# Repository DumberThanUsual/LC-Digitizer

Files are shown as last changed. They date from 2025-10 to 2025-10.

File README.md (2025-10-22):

# LC Resonator Locator and Digitizer



## Second Year Group Project Hardware Element

This project is the hardware input element of my second year FPGA group project. 
The FPGA part was a hardware accelerated complex function plotter, taking coordinates of poles and zeros on the complex plane as inputs and displaying the result on an HDMI display.
The input hardware is a board that detects the positions of tokens that represent poles and zeros of different orders which can be placed on the board.

## Theory of Operation



The tokens are a capacitor and inductor in paralell, forming an LC resonator. The inductor is unshielded, allowing it to interact with external magnetic fields. 
They can be caused to resonate by an electromagnetic impulse generated by placing it on a coil and sending a pusle of current through it. 
The presence of the token can be detected by measuring the voltage on the coil after the original impulse and looking for the resonant frequency of the resonator.

Using this for detection and location of the tokens can be done by separating and multiplexing the detection loops into transmission and reception loops.
These loops can be elongated and placed perpendicularly on opposite sides of a PCB. Pulsing one Tx loop and listening on all Rx loops measures token presence on one row and scanning all Tx coils reveals the entire plane.

Measurement of tokens not located exactly within one intersection (cell) of Tx and Rx coils is done by measuring the amplitude of a cluster of responses and adjusting the final position proportionally. 
This requires the minimum spacing between tokens to be greater than twice the width of the coils.

Differentiating between types of tokens, representing differing orders of the poles and zeros, is done by varying the resonant frequencies of the tokens and measuring this in the response.

## Issues and Reflections

This project was designed with little time for development and refinement. The PCB had to be ordered within 2 weeks of the project start, with no second revision. This means there are some (very questionable) quirks in the design, including:
- "Row Amplifers": After some debate, we did not want to risk the expected sub-millivolt signal being lost in the multiplexers. To be safe, we added a 20dB amplifier for every row.
  Not only was the signal much larger than measured in the prototype, but the multiplexers do not affect the signal in a meaningful way. The capacitor between the gain-setting resistors and the reference is not necessary and nor is the entire row amplifier circuit.
  This saves 8 ICs, lots of board space and some cost.

- Slow loop driver ICs: The loop driver ICs are pulsed by pulsing their sleep pins, not the input pins. We did not read the datasheet properly - these ICs take 30µs to wake from sleep.
  Given this needs to be done 128 times per scan, at multiple scans per second, this is a big limiting factor in the update rate.
  Instead, the sleep pins should be tied low and the OE pins on the shift registers be pulsed instead.

- Slow OLED: The oled is of the I2C variety, running at 400kHz. Using a non-DMA library to drive it, this is very slow and stops the UI task from properly reading the rotary encoder inputs.

- Suicidal power managment: If there is a glitch in the power supply, it seems to be possible that the shift registers and driver ICs can be set to drive a loop, shorting the supply to ground and browning out the µC and preventing it from turning off the drivers.
  This does not cause damage to the board, but the power needs to be recycled before it will work again and is very annoying.

- Substandard firmware: The firmware became progressivly more rushed as time went on. This is especially visible in the liberal use of ```nop``` delays instead of proper freeRTOS and timer delays.

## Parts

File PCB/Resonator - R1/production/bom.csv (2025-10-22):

Designator | Footprint | Quantity | Value | LCSC Part #
C101 | 0603 | 1 | 62p
C103 | 0603 | 1 | 12p
C104 | 0603 | 1 | 27p
C105 | 0603 | 1 | 39p
C106 | 0603 | 1 | 56p
C107 | 0603 | 1 | 82p
C108 | 0603 | 1 | 120p
C109 | 0603 | 1 | 160p
C110 | 0603 | 1 | 220p
L101 | L | 1 | 1m
TP101, TP102 | 5mm 112.5 | 2 | TestPoint
TP103, TP104, TP105, TP106, TP107, TP108, TP109, TP110 | 7mm 20 | 8 | TestPoint

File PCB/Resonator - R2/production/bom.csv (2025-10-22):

Designator | Footprint | Quantity | Value | LCSC Part #
TP101, TP102 | TestPoint_Pad_D1.0mm | 2 | TestPoint

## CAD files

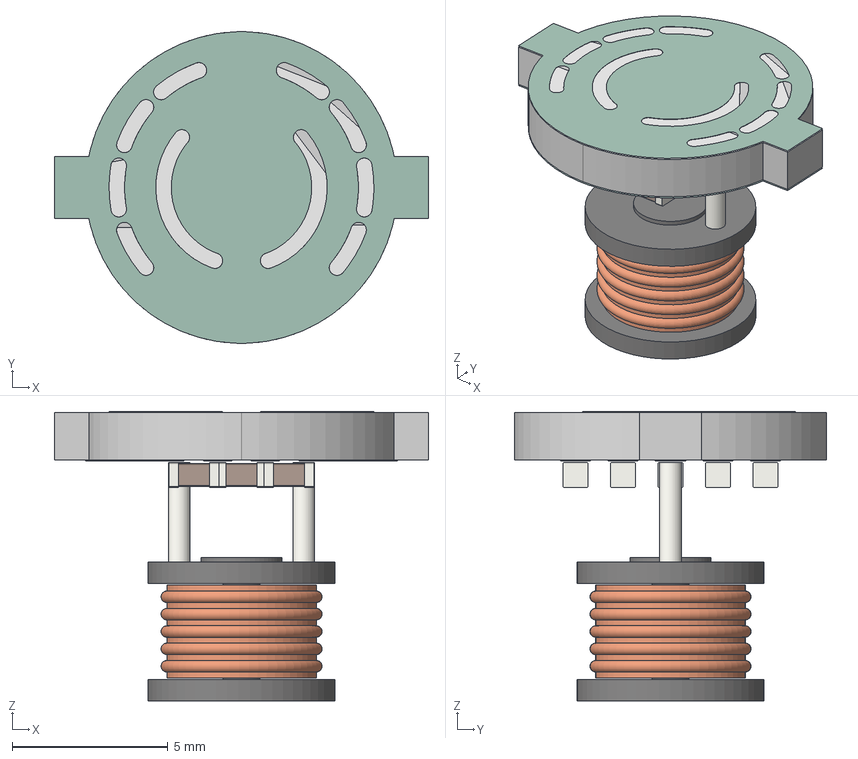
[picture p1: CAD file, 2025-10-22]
PCB/Resonator - R1/Resonator - R1.step
12.0 x 10.00 x 9.30 mm
C_0603_1608Metric x 9
L_Radial_D6.0mm_P4.00mm
Resonator - R1_pad
Resonator - R1_silkscreen
Resonator - R1_soldermask
Resonator - R1_PCB

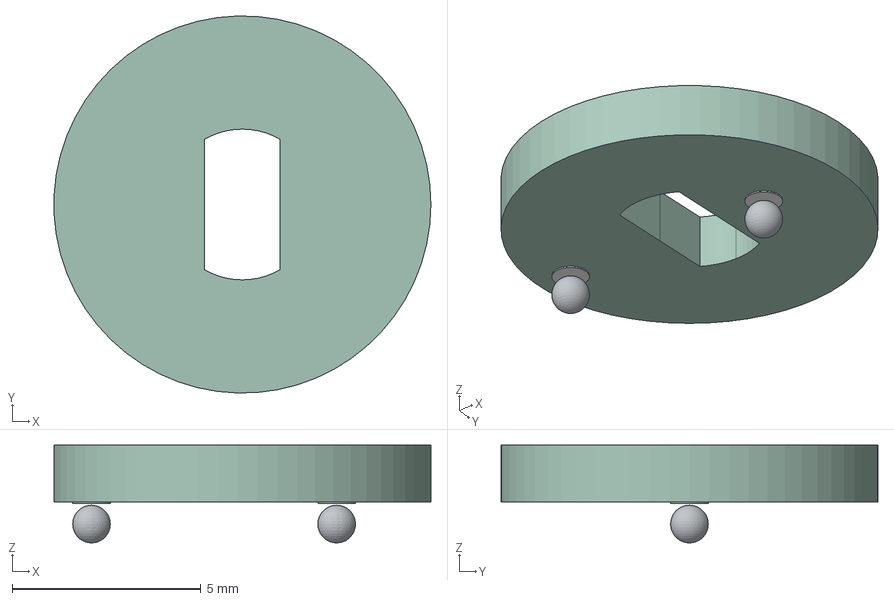
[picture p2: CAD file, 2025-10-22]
PCB/Resonator - R2/Resonator - R2.step
9.99 x 10.00 x 2.59 mm
Resonator - R2_pad
Resonator - R2_PCB

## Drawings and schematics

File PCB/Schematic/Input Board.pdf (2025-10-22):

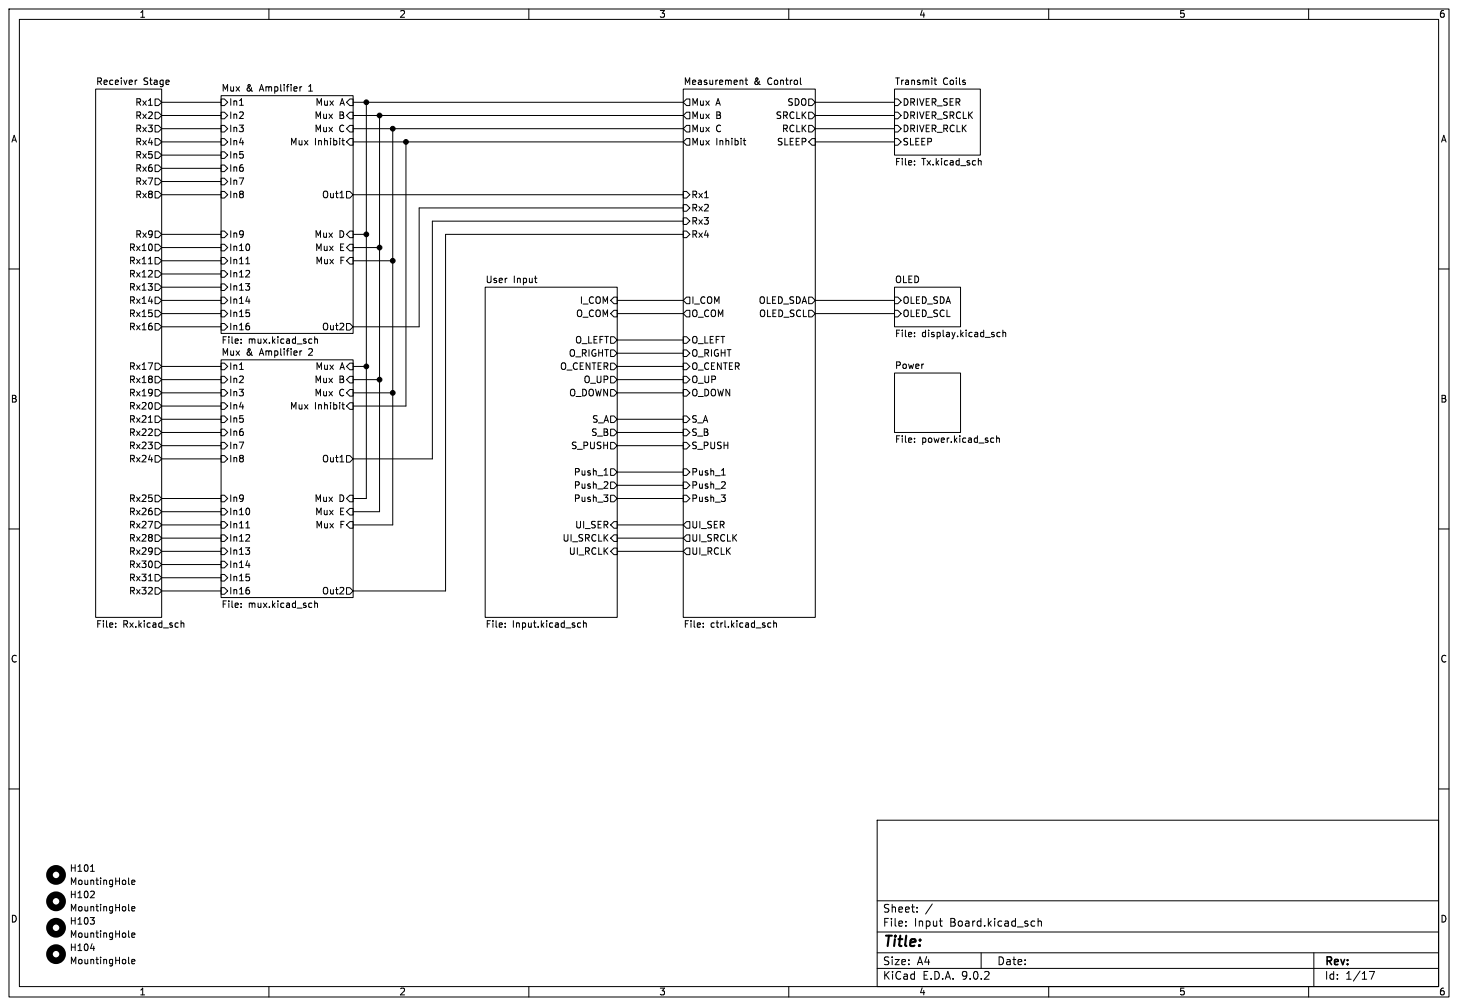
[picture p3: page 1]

Transmit Coils File: Tx.kicad_sch

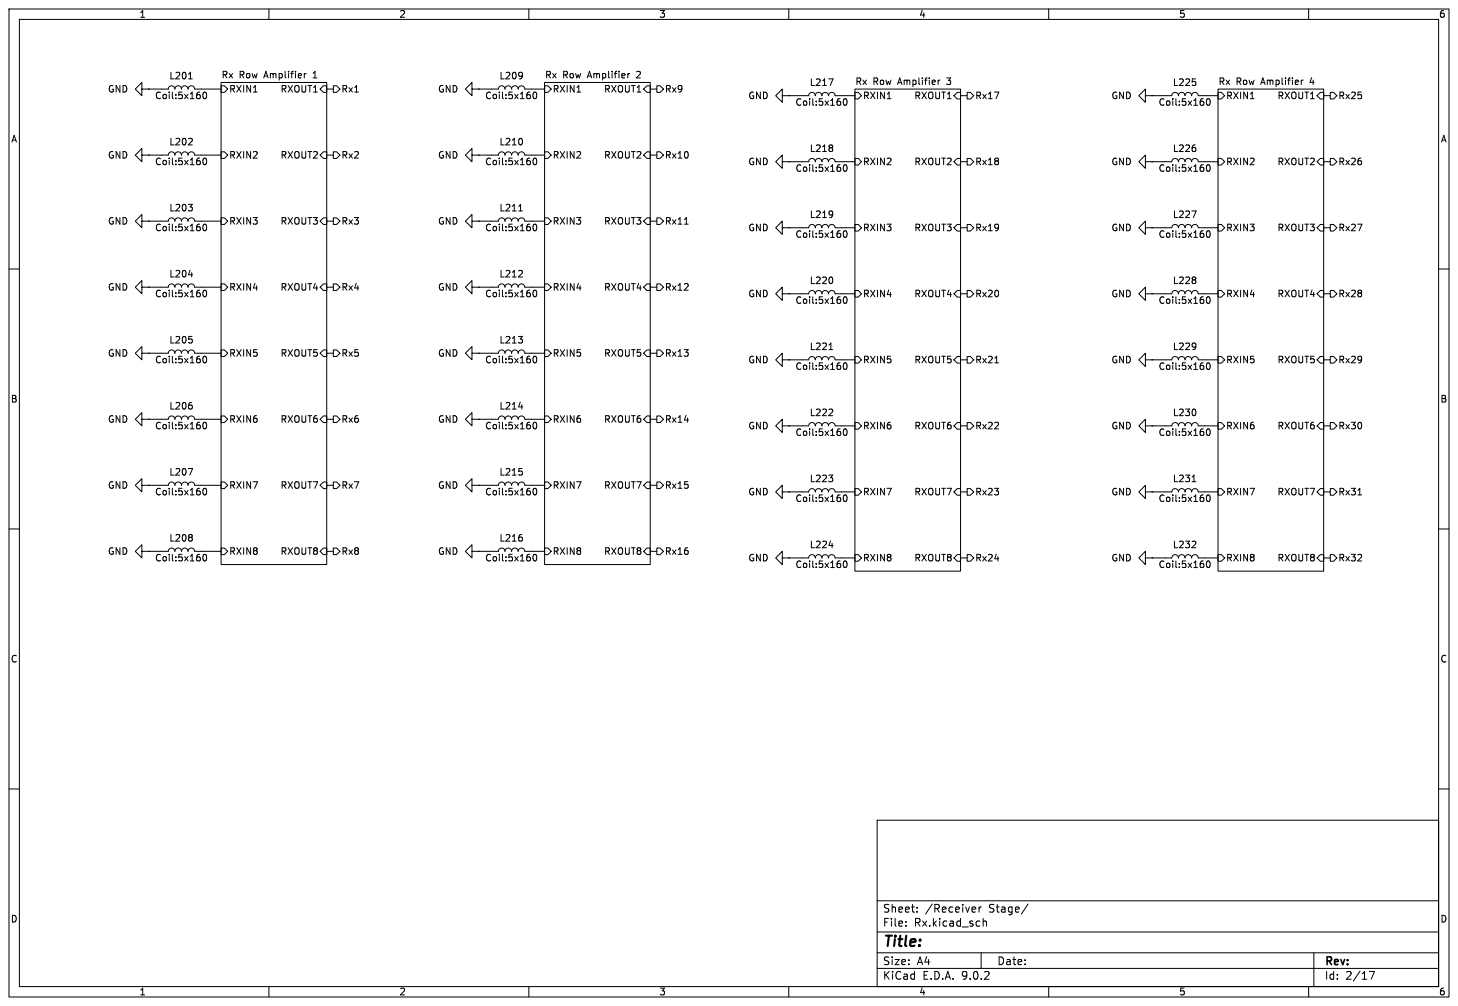
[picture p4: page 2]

L225 Coil:5x160 GND GND GND GND

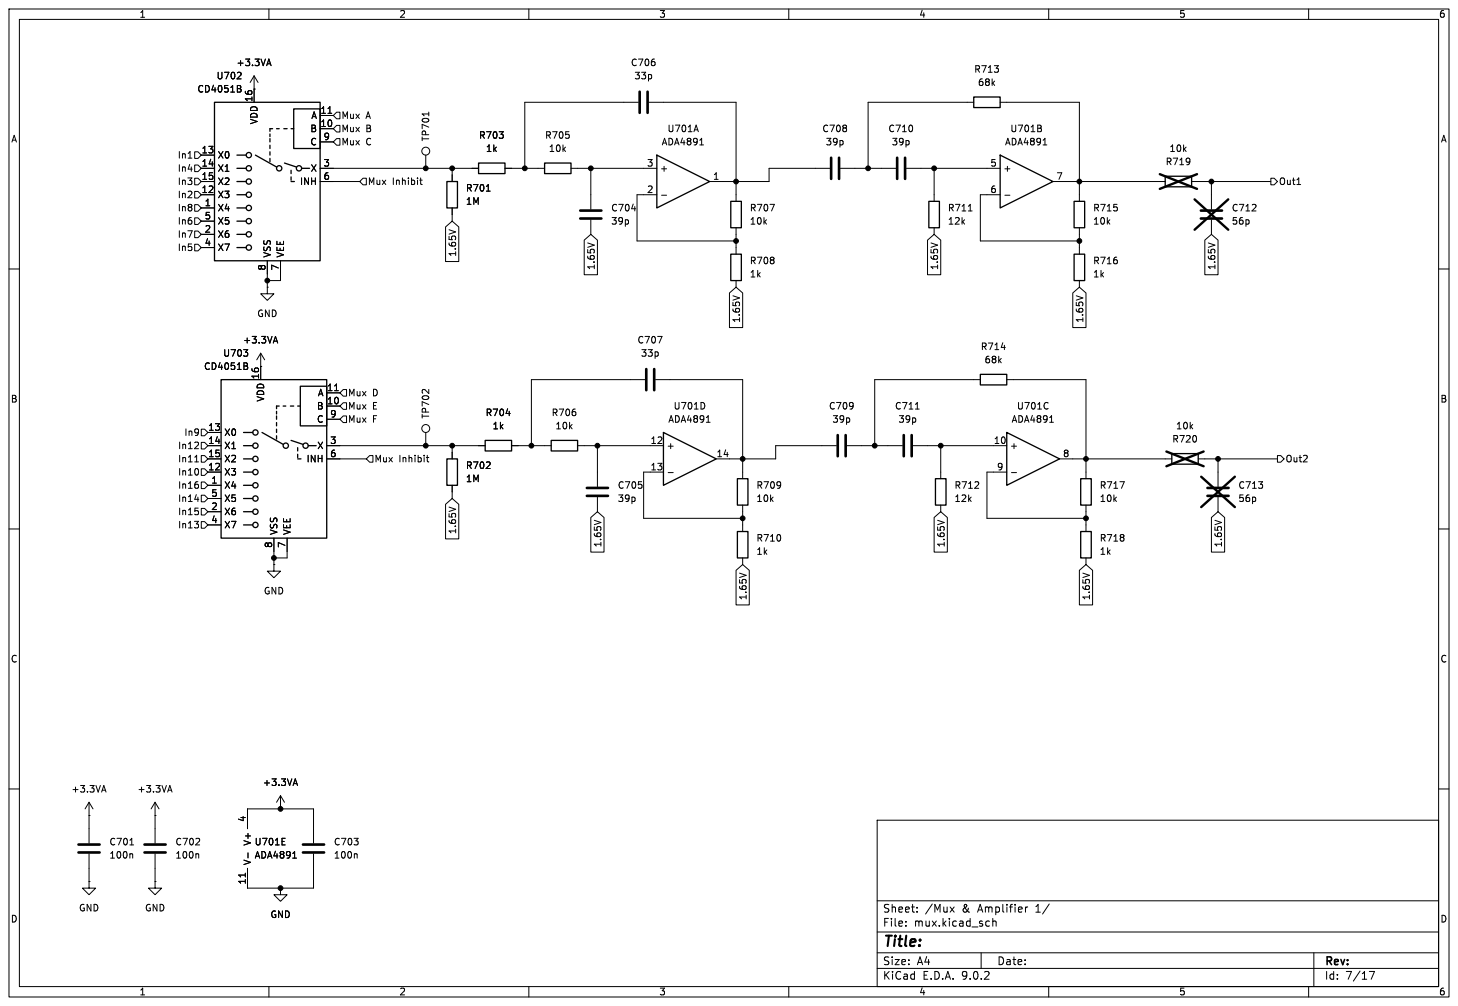
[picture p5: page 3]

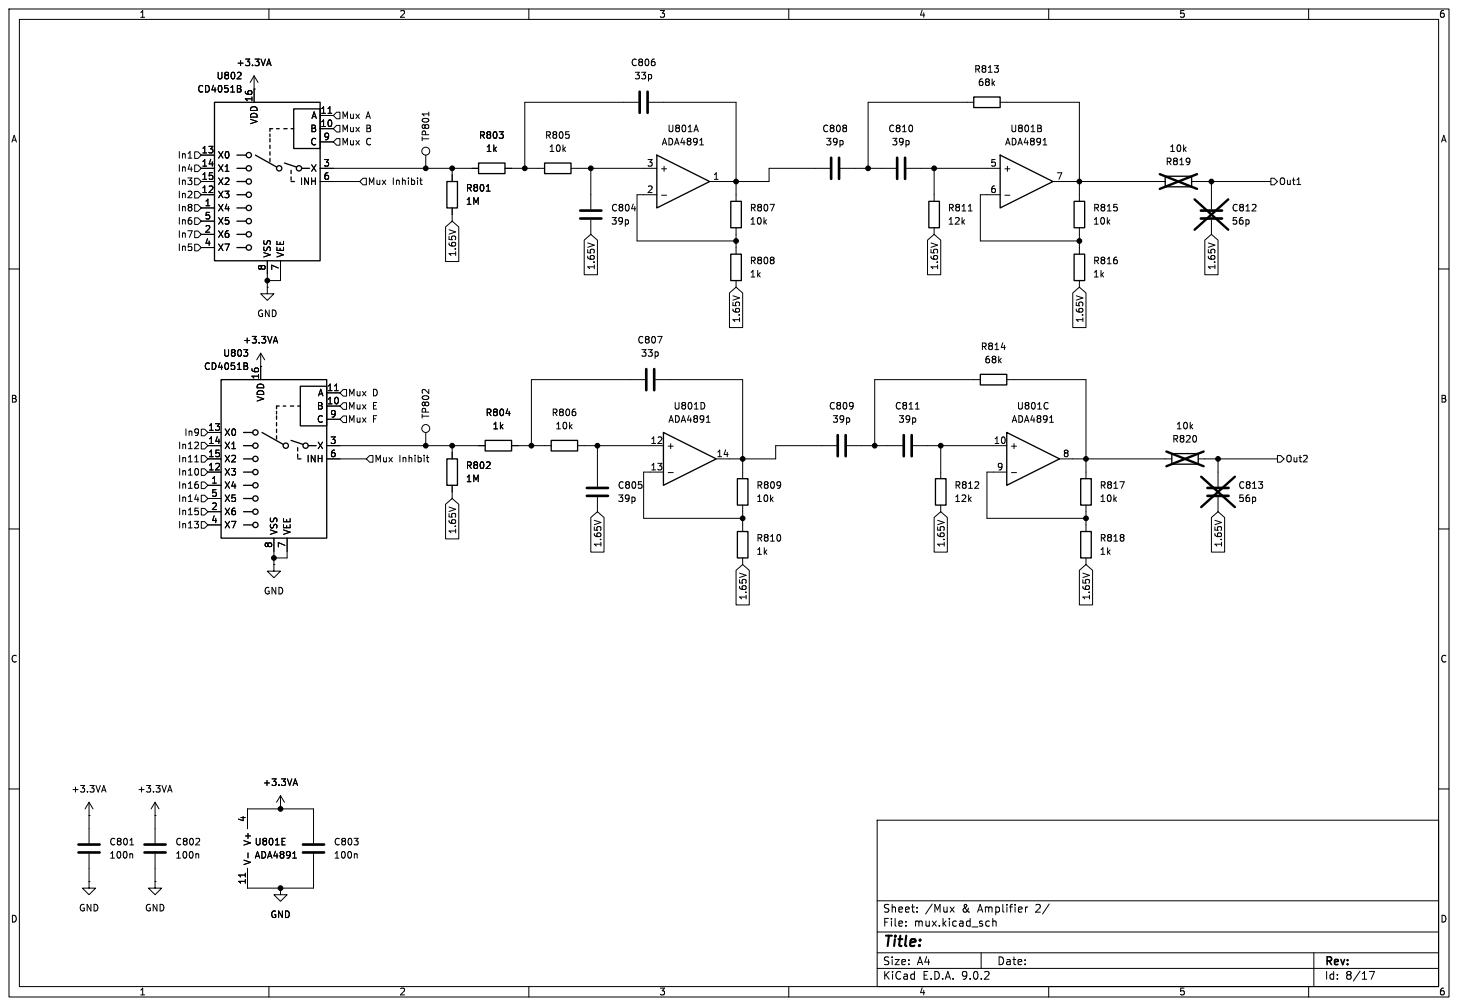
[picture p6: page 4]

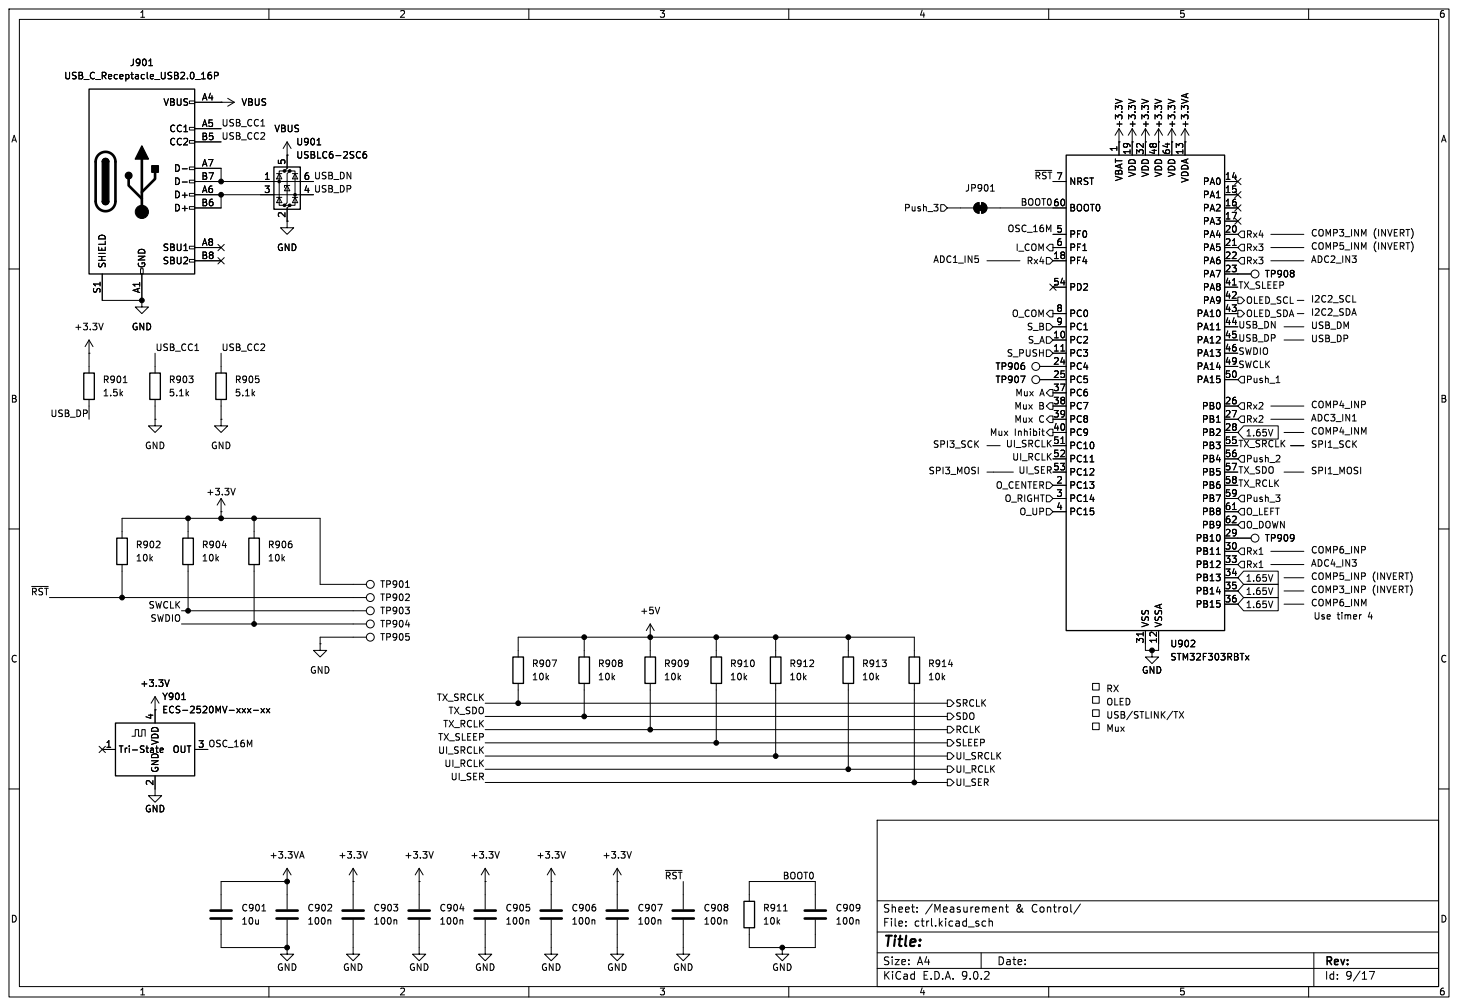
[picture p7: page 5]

1 VDD 19 VDD 32 VSS 31 VDD 48 VSSA 12 VDD 64 VDDA 13 PA0 14 PA1 15 PA2 16 PA3 17 PA4 20 PA5 21 PA6 22 PA7 23 PA8 41 PA9 42 PA10 43 PA11 44 PA12 45 PA13 46 PA14 49 PA15 50 PB0 26 PB1 27 PB2 28 PB3 55 PB4 56 PB5 57 PB6 58 PB7 59 PB8 61 PB9 62 PB10 29 PB11 30 PB12 33 PB13 34 PB14 35 PB15 36 U902 STM32F303RBTx +5V GND +3.3V +3.3V

1 VDD 19 VDD 32 VSS 31 VDD 48 VSSA 12 VDD 64 VDDA 13 PA0 14 PA1 15 PA2 16 PA3 17 PA4 20 PA5 21 PA6 22 PA7 23 PA8 41 PA9 42 PA10 43 PA11 44 PA12 45 PA13 46 PA14 49 PA15 50 PB0 26 PB1 27 PB2 28 PB3 55 PB4 56 PB5 57 PB6 58 PB7 59 PB8 61 PB9 62 PB10 29 PB11 30 PB12 33 PB13 34 PB14 35 PB15 36 TP909 TP908 TP906 TP907

2 OUT 3 Y901 ECS-2520MV-xxx-xx GND

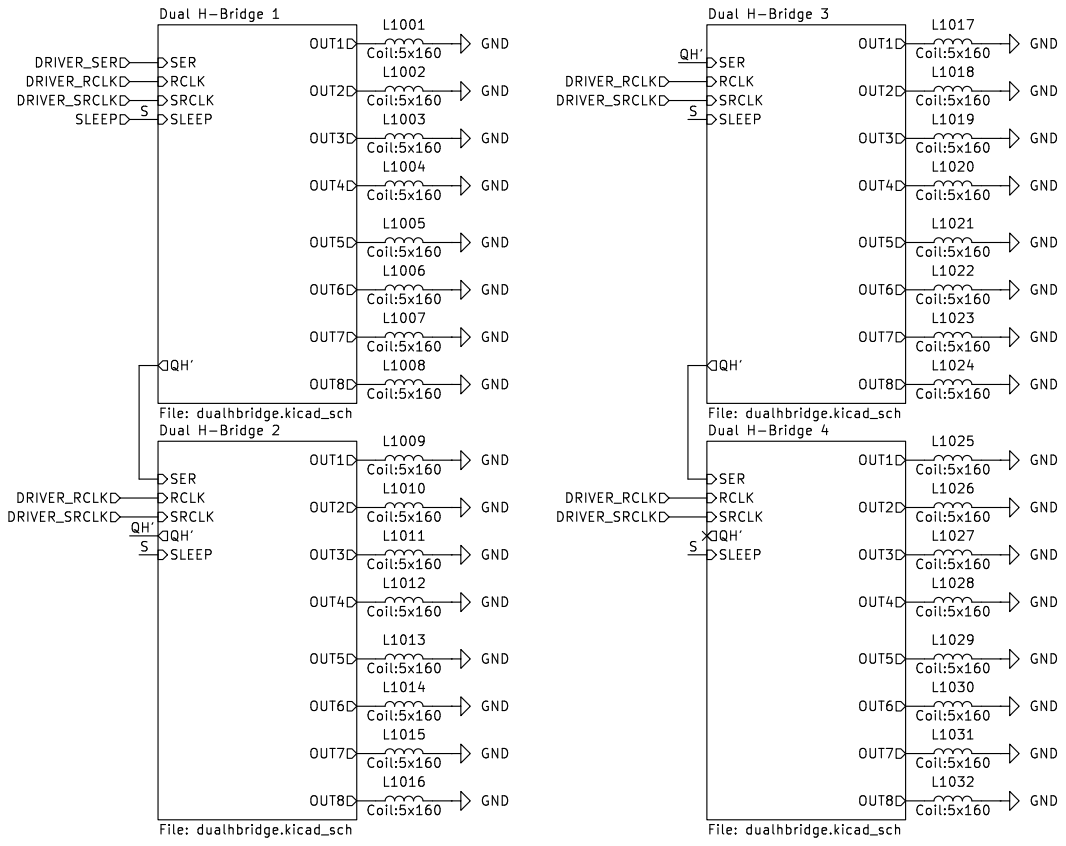
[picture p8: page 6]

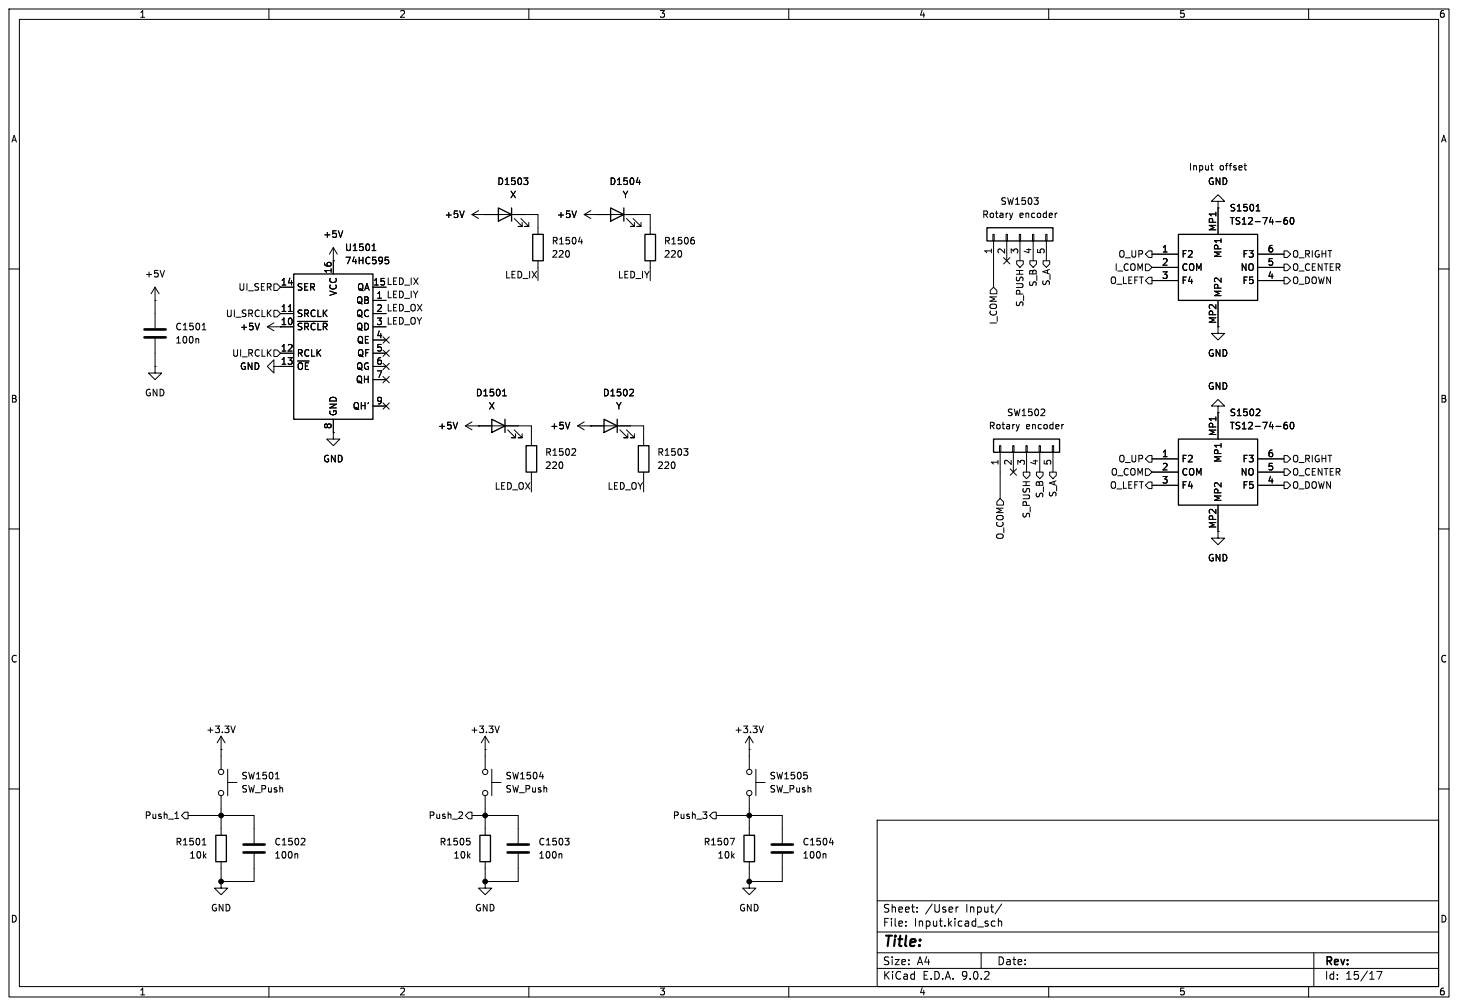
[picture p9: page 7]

8 QA 15 QB 1 QC 2 QD 3 QE 4 QF 5 QG 6 QH 7 QH' 9 +5V GND

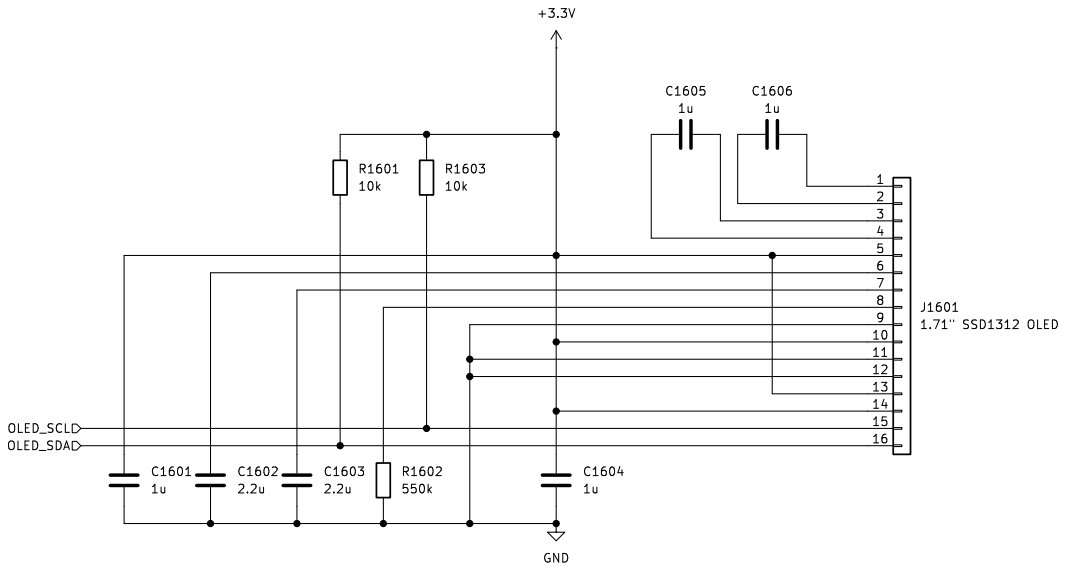
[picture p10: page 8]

10
11
12
13

Id: 16/17 Title: File: display.kicad_sch Sheet: /OLED/ R1602

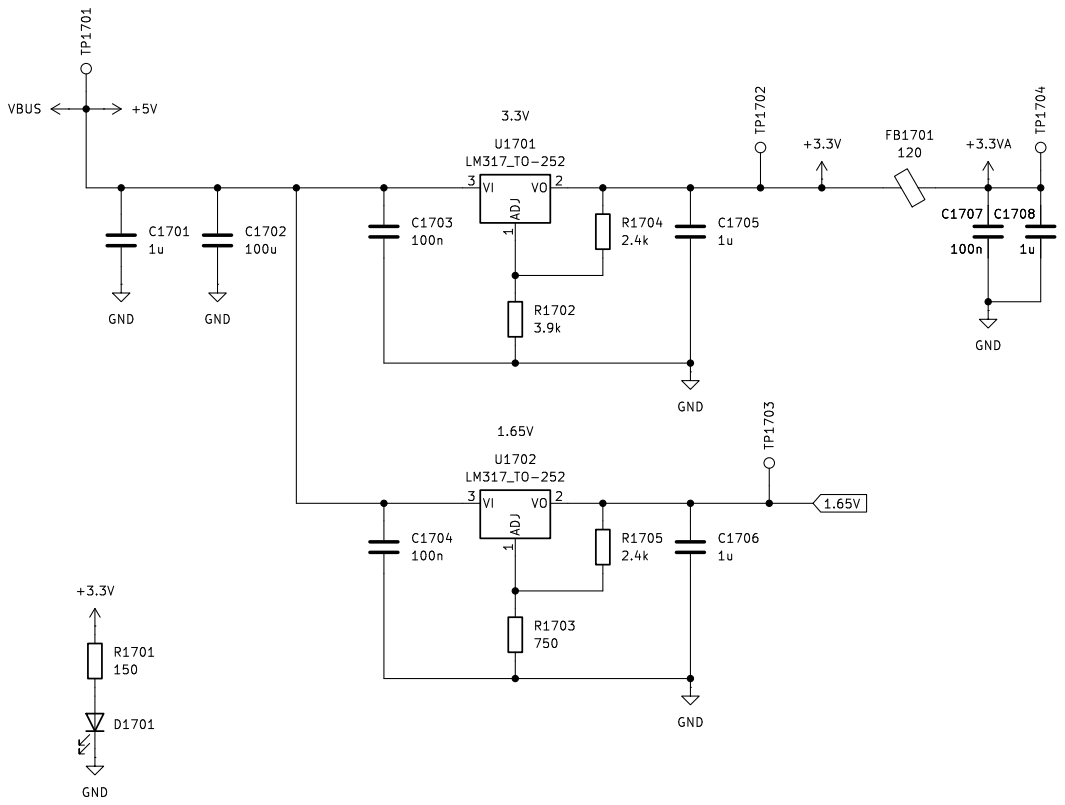
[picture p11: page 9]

Id: 17/17 Title: File: power.kicad_sch Sheet: /Power/

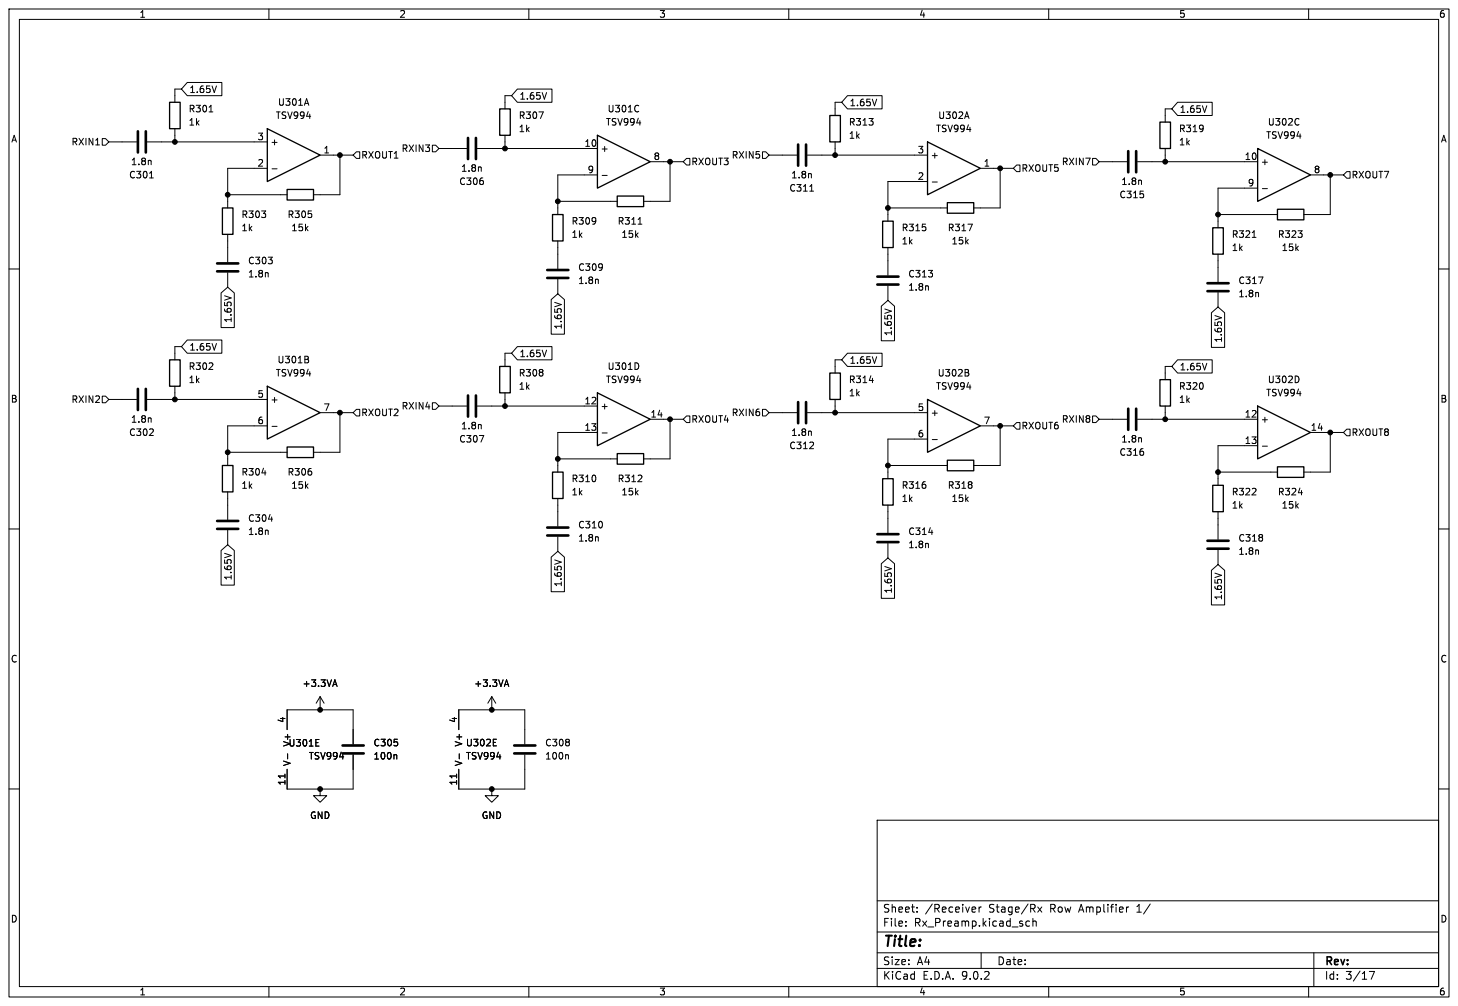
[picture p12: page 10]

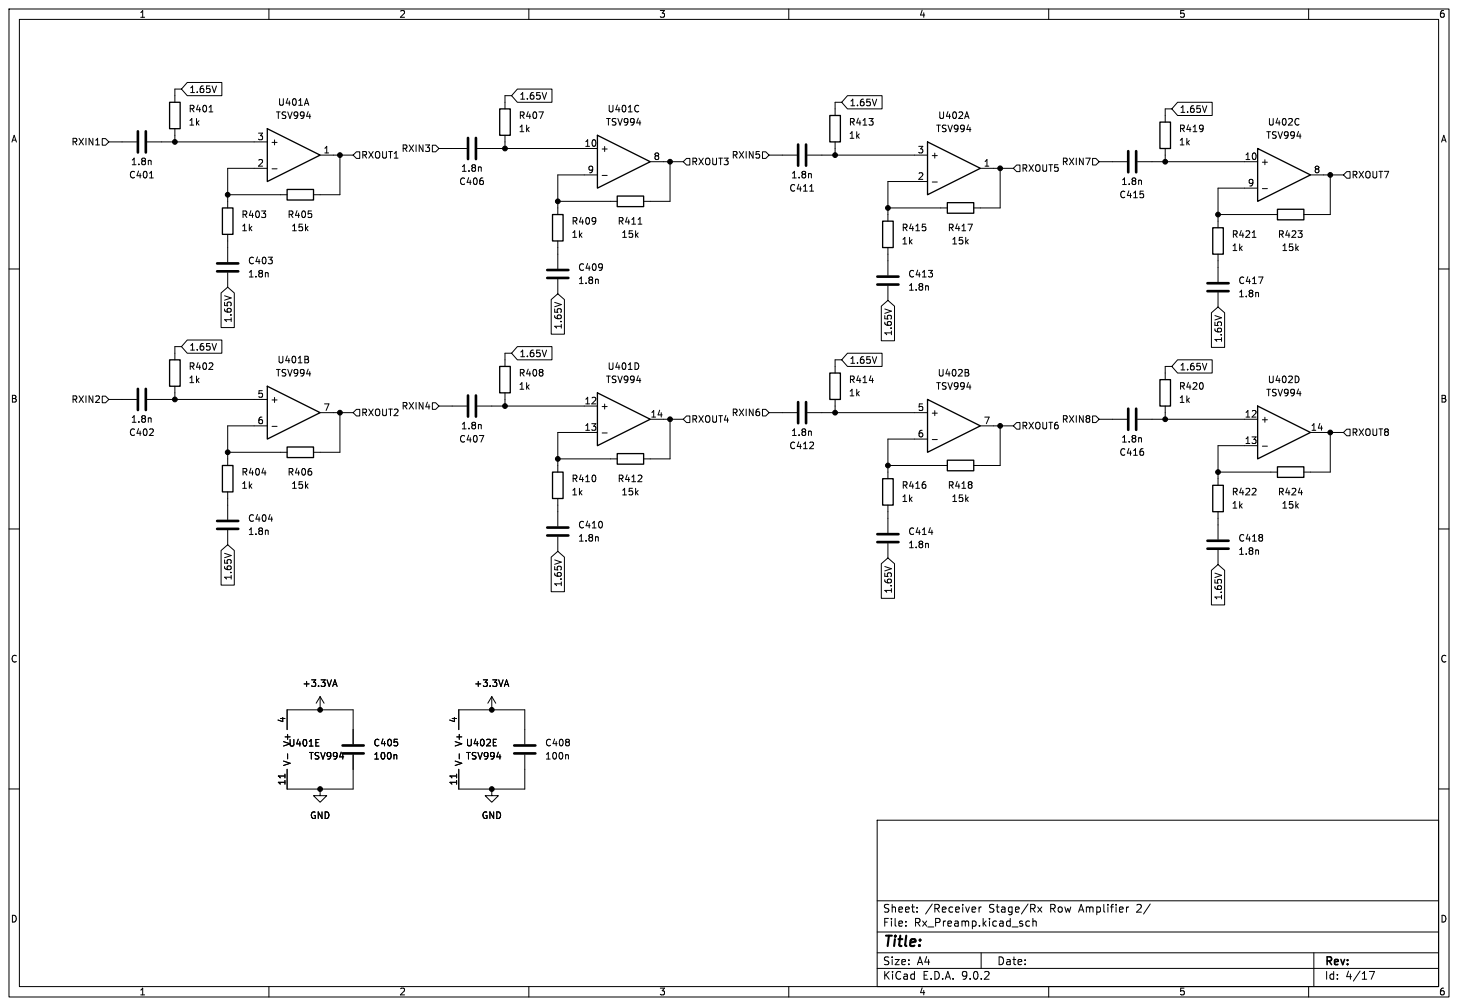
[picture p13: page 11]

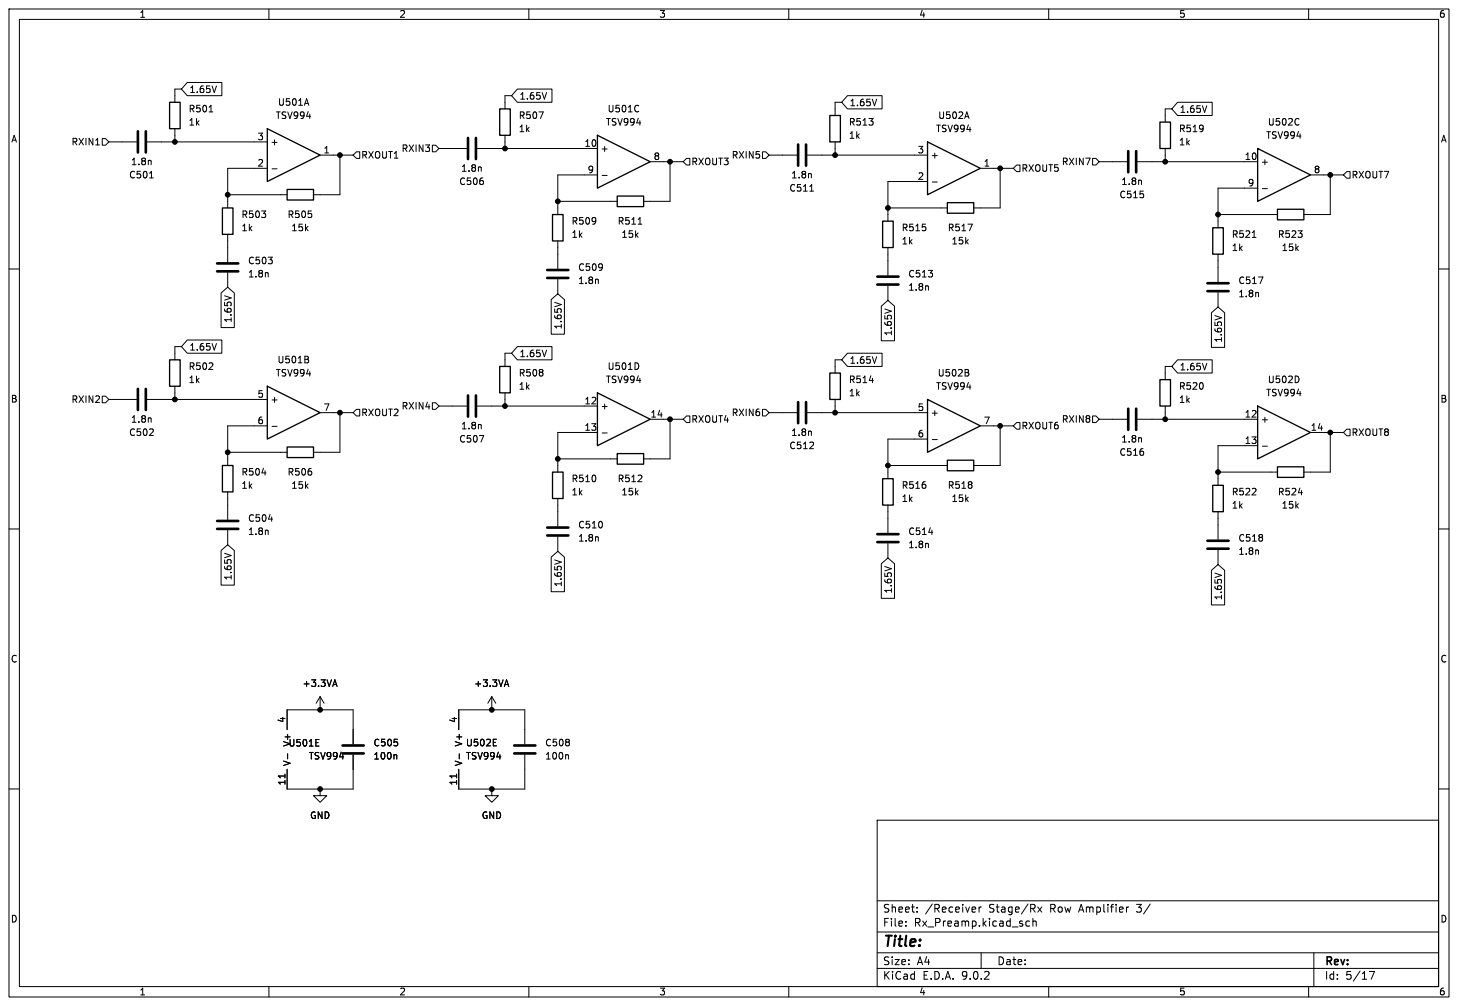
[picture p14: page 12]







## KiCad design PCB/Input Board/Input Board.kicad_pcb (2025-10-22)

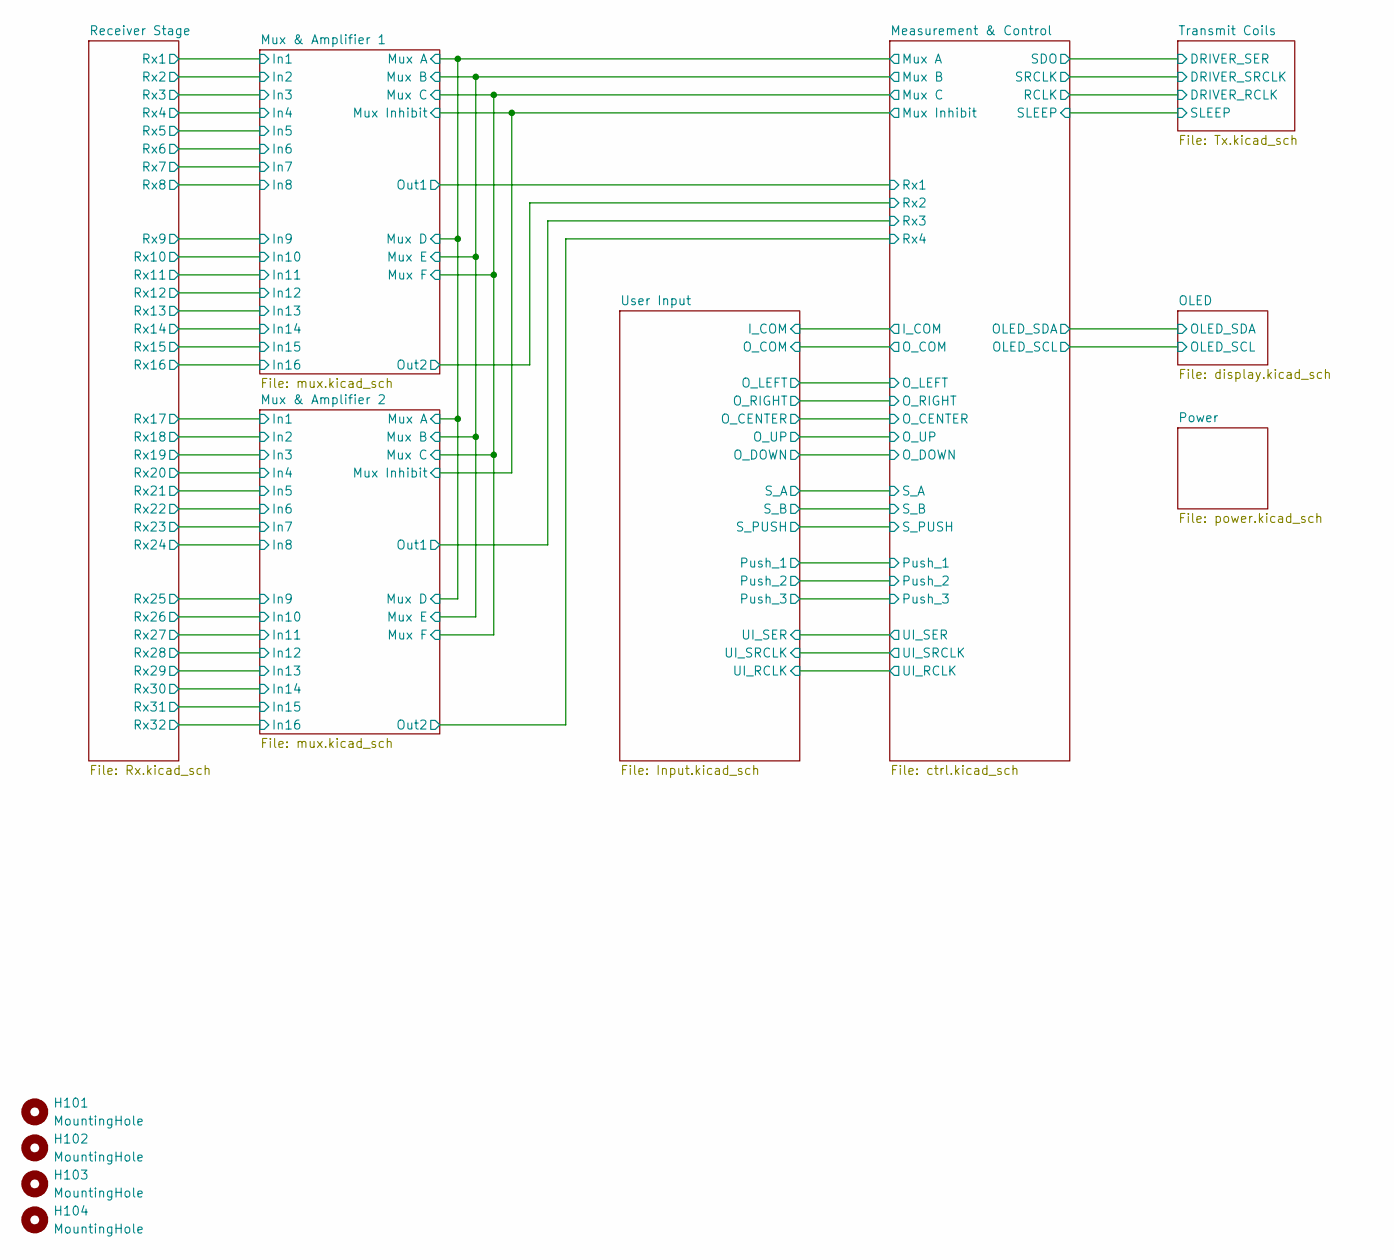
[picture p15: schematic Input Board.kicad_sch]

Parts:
H101, H102, H103, H104: MountingHole; MountingHole_3.2mm_M3

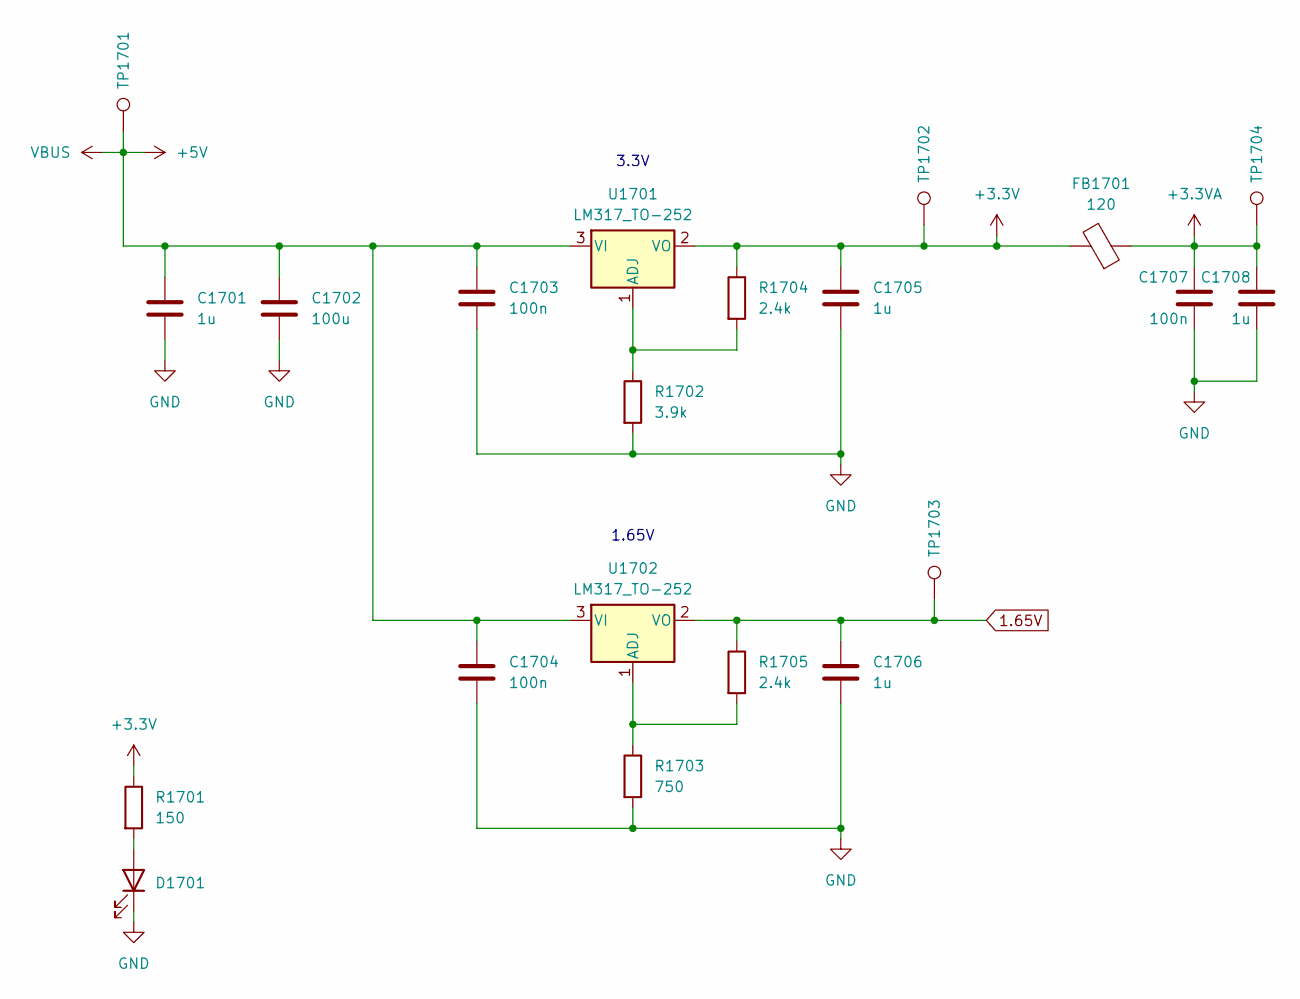
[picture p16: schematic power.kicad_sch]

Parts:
C1701, C1705, C1706: 1u; C_0603_1608Metric
C1702: 100u; C_Elec_4x5.8
C1703, C1704: 100n; C_0603_1608Metric
C1707: 100n; C_0603_1608Metric; Manufacturer Part Number CL05B104KB54PNC; JLC Part Type Basic
C1708: 1u; C_0603_1608Metric; Manufacturer Part Number CL21B105KBFNNNE; JLC Part Type Basic
D1701: LED_0603_1608Metric
FB1701: 120; L_1206_3216Metric
R1701: 150; R_0603_1608Metric
R1702: 3.9k; R_0603_1608Metric
R1703: 750; R_0603_1608Metric
R1704, R1705: 2.4k; R_0603_1608Metric
TP1701, TP1702, TP1703, TP1704: TestPoint; TestPoint_Pad_1.5x1.5mm
U1701, U1702: LM317_TO-252; SOT-89-3

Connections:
1.65V: C1706.1, R1705.1, TP1703.1, U1702.2 (VO); also elsewhere on the board
+3.3V: C1705.1, FB1701.2, R1701.1, R1704.1, TP1702.1, U1701.2 (VO); also elsewhere on the board
+3.3VA: C1707.1, C1708.1, FB1701.1, TP1704.1; also elsewhere on the board
+5V: C1701.1, C1702.1, C1703.1, C1704.1, TP1701.1, U1701.3 (VI), U1702.3 (VI); also elsewhere on the board
GND: C1701.2, C1702.2, C1703.2, C1704.2, C1705.2, C1706.2, C1707.2, C1708.2, D1701.1 (K), R1702.2, R1703.2; also elsewhere on the board
unnamed: D1701.2 (A), R1701.2
unnamed: R1702.1, R1704.2, U1701.1 (ADJ)
unnamed: R1703.1, R1705.2, U1702.1 (ADJ)

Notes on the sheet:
1.65V
3.3V

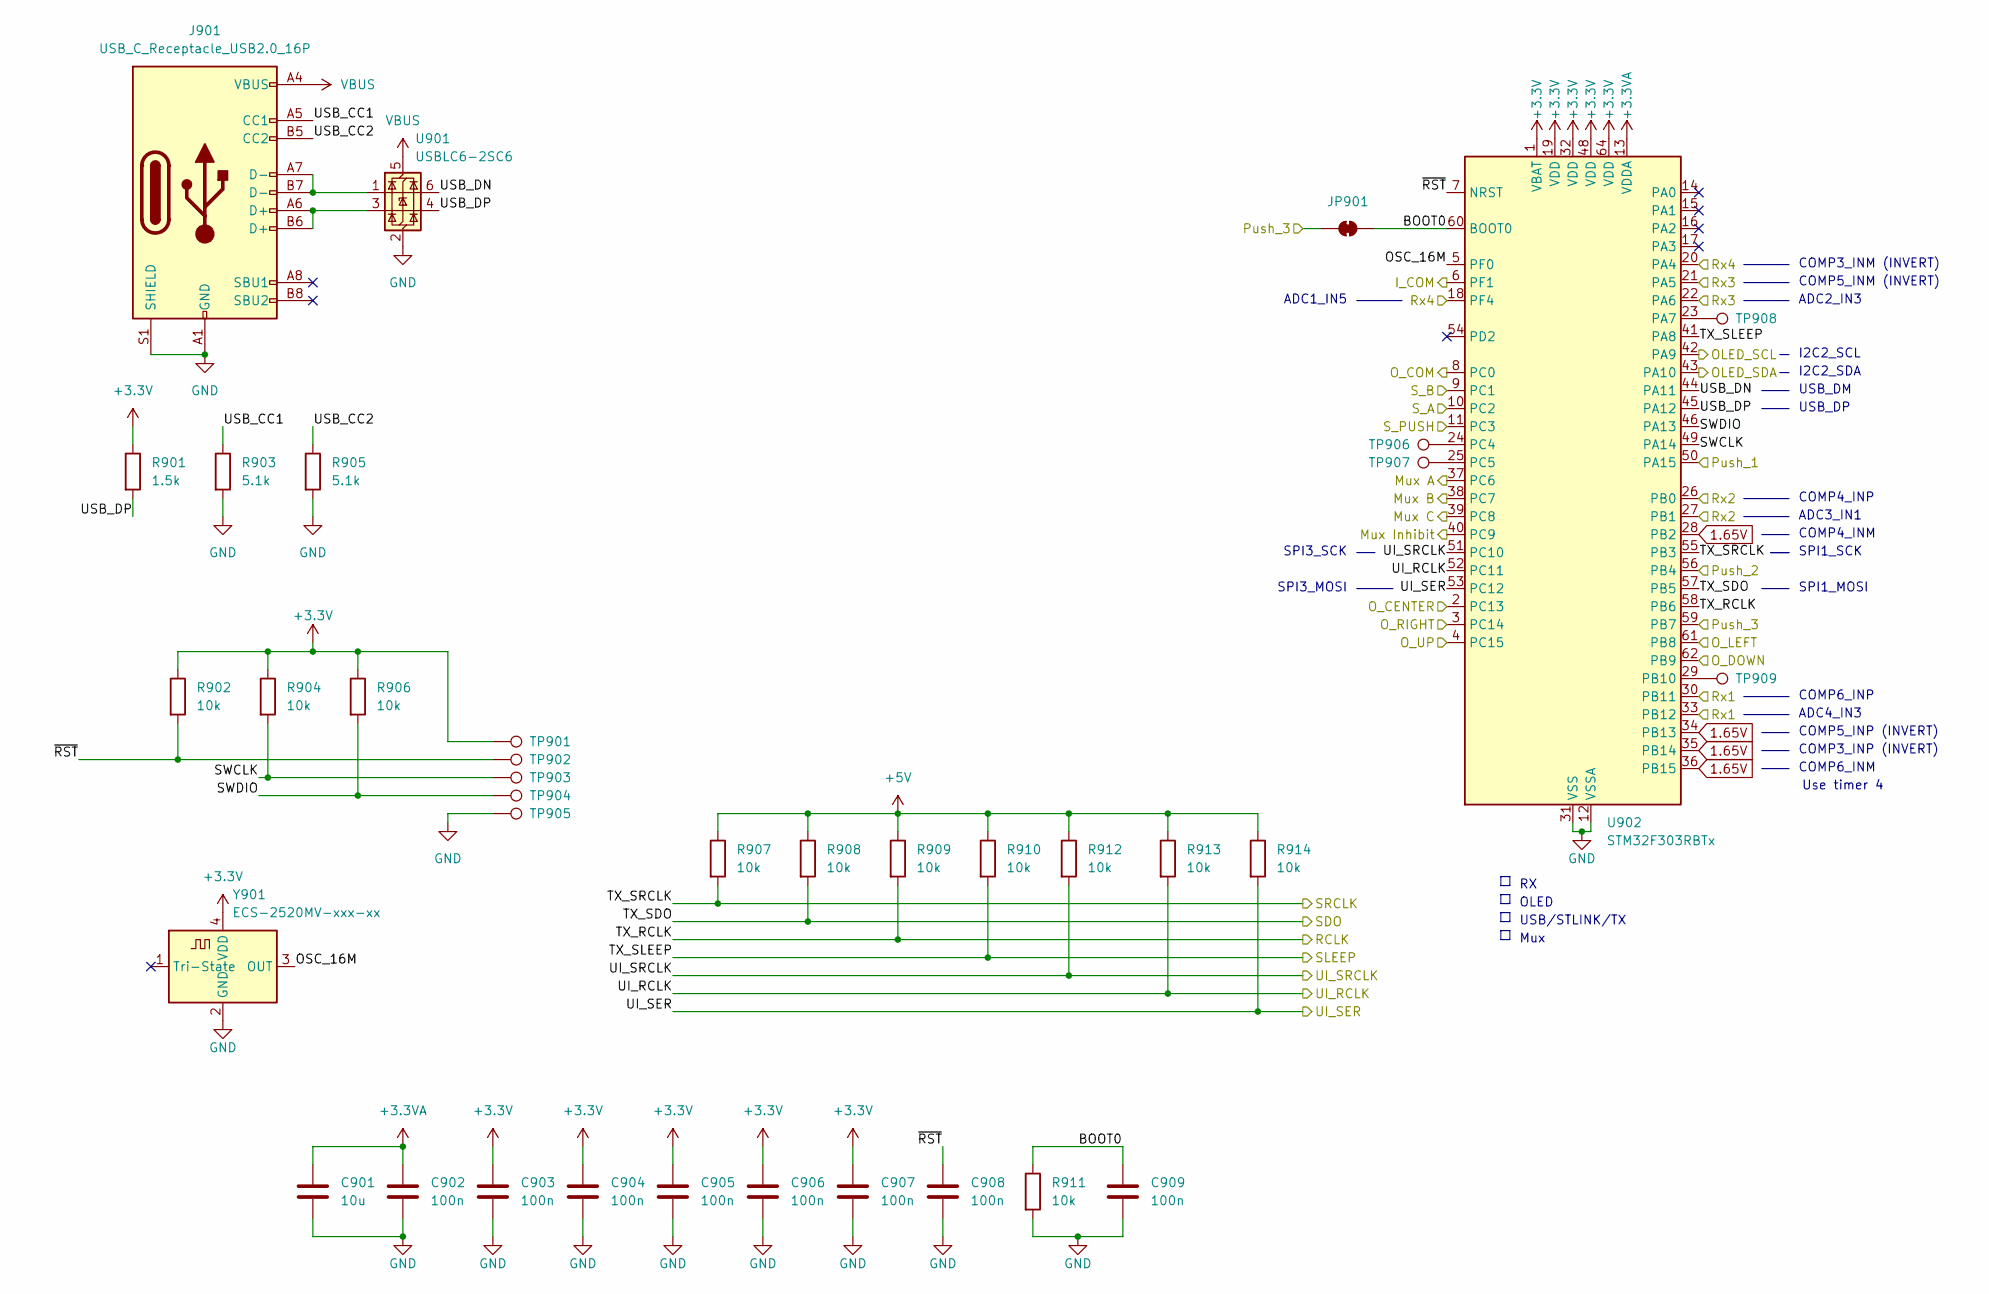
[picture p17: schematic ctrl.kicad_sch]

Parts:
C901: 10u; C_0603_1608Metric
C902, C903, C904, C905, C906, C907, C908, C909: 100n; C_0603_1608Metric
J901: USB_C_Receptacle_USB2.0_16P; USB_C_Receptacle_GCT_USB4110
JP901: SolderJumper_2_Bridged; SolderJumper-2_P1.3mm_Bridged_RoundedPad1.0x1.5mm
R901: 1.5k; R_0603_1608Metric
R902, R904, R906, R907, R908, R909, R910, R911, R912, R913, R914: 10k; R_0603_1608Metric
R903, R905: 5.1k; C_0603_1608Metric
TP901, TP902, TP903, TP904, TP905, TP906, TP907, TP908, TP909: TestPoint; TestPoint_Pad_1.5x1.5mm
U901: USBLC6-2SC6; SOT-23-6
U902: STM32F303RBTx; LQFP-64_10x10mm_P0.5mm
Y901: ECS-2520MV-xxx-xx; Oscillator_SMD_ECS_2520MV-xxx-xx-4Pin_2.5x2.0mm

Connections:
1.65V: U902.28 (PB2), U902.34 (PB13), U902.35 (PB14), U902.36 (PB15); also elsewhere on the board
+3.3V: C903.1, C904.1, C905.1, C906.1, C907.1, R901.1, R902.1, R904.1, R906.1, TP901.1, U902.1 (VBAT), U902.19 (VDD), U902.32 (VDD), U902.48 (VDD), U902.64 (VDD), Y901.4 (VDD); also elsewhere on the board
+3.3VA: C901.1, C902.1, U902.13 (VDDA); also elsewhere on the board
+5V: J901.A4 (VBUS), J901.A9 (VBUS), J901.B4 (VBUS), J901.B9 (VBUS), R907.1, R908.1, R909.1, R910.1, R912.1, R913.1, R914.1, U901.5 (VBUS); also elsewhere on the board
/Measurement & Control/BOOT0: C909.1, JP901.2 (B), R911.1, U902.60 (BOOT0)
/Measurement & Control/I_COM: U902.6 (PF1); also elsewhere on the board
/Measurement & Control/Mux A: U902.37 (PC6); also elsewhere on the board
/Measurement & Control/Mux B: U902.38 (PC7); also elsewhere on the board
/Measurement & Control/Mux C: U902.39 (PC8); also elsewhere on the board
/Measurement & Control/Mux Inhibit: U902.40 (PC9); also elsewhere on the board
/Measurement & Control/OLED_SCL: U902.42 (PA9); also elsewhere on the board
/Measurement & Control/OLED_SDA: U902.43 (PA10); also elsewhere on the board
/Measurement & Control/OSC_16M: U902.5 (PF0), Y901.3 (OUT)
/Measurement & Control/O_CENTER: U902.2 (PC13); also elsewhere on the board
/Measurement & Control/O_COM: U902.8 (PC0); also elsewhere on the board
/Measurement & Control/O_DOWN: U902.62 (PB9); also elsewhere on the board
/Measurement & Control/O_LEFT: U902.61 (PB8); also elsewhere on the board
/Measurement & Control/O_RIGHT: U902.3 (PC14); also elsewhere on the board
/Measurement & Control/O_UP: U902.4 (PC15); also elsewhere on the board
/Measurement & Control/Push_1: U902.50 (PA15); also elsewhere on the board
/Measurement & Control/Push_2: U902.56 (PB4); also elsewhere on the board
/Measurement & Control/Push_3: JP901.1 (A), U902.59 (PB7); also elsewhere on the board
/Measurement & Control/Rx1: U902.30 (PB11), U902.33 (PB12); also elsewhere on the board
/Measurement & Control/Rx2: U902.26 (PB0), U902.27 (PB1); also elsewhere on the board
/Measurement & Control/Rx3: U902.21 (PA5), U902.22 (PA6); also elsewhere on the board
/Measurement & Control/Rx4: U902.18 (PF4), U902.20 (PA4); also elsewhere on the board
/Measurement & Control/SWCLK: R904.2, TP903.1, U902.49 (PA14)
/Measurement & Control/SWDIO: R906.2, TP904.1, U902.46 (PA13)
/Measurement & Control/S_A: U902.10 (PC2); also elsewhere on the board
/Measurement & Control/S_B: U902.9 (PC1); also elsewhere on the board
/Measurement & Control/S_PUSH: U902.11 (PC3); also elsewhere on the board
/Measurement & Control/TX_RCLK: R909.2, U902.58 (PB6); also elsewhere on the board
/Measurement & Control/TX_SDO: R908.2, U902.57 (PB5); also elsewhere on the board
/Measurement & Control/TX_SLEEP: R910.2, U902.41 (PA8); also elsewhere on the board
/Measurement & Control/TX_SRCLK: R907.2, U902.55 (PB3); also elsewhere on the board
/Measurement & Control/UI_RCLK: R913.2, U902.52 (PC11); also elsewhere on the board
/Measurement & Control/UI_SER: R914.2, U902.53 (PC12); also elsewhere on the board
/Measurement & Control/UI_SRCLK: R912.2, U902.51 (PC10); also elsewhere on the board
/Measurement & Control/USB_CC1: J901.A5 (CC1), R903.1
/Measurement & Control/USB_CC2: J901.B5 (CC2), R905.1
/Measurement & Control/USB_DN: U901.6 (I/O1), U902.44 (PA11)
/Measurement & Control/USB_DP: R901.2, U901.4 (I/O2), U902.45 (PA12)
/Measurement & Control/~RST: C908.1, R902.2, TP902.1, U902.7 (NRST)
GND: C901.2, C902.2, C903.2, C904.2, C905.2, C906.2, C907.2, C908.2, C909.2, J901.A1 (GND), J901.A12 (GND), J901.B1 (GND), J901.B12 (GND), J901.S1 (SHIELD), R903.2, R905.2, R911.2, TP905.1, U901.2 (GND), U902.12 (VSSA), U902.31 (VSS), U902.47 (VSS), U902.63 (VSS), Y901.2 (GND); also elsewhere on the board
unnamed: J901.A6 (D+), J901.B6 (D+), U901.3 (I/O2)
unnamed: J901.A7 (D-), J901.B7 (D-), U901.1 (I/O1)
unnamed: TP908.1, U902.23 (PA7)
unnamed: TP909.1, U902.29 (PB10)
unnamed: TP906.1, U902.24 (PC4)
unnamed: TP907.1, U902.25 (PC5)

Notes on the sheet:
SPI3_SCK
SPI1_MOSI
COMP5_INM (INVERT)
ADC4_IN3
COMP3_INP (INVERT)
ADC3_IN1
COMP5_INP (INVERT)
COMP4_INP
I2C2_SCL
SPI1_SCK
ADC2_IN3
COMP3_INM (INVERT)
USB_DP
USB/STLINK/TX
COMP6_INP
ADC1_IN5
COMP4_INM
Use timer 4
SPI3_MOSI
OLED
Mux
USB_DM
COMP6_INM
I2C2_SDA

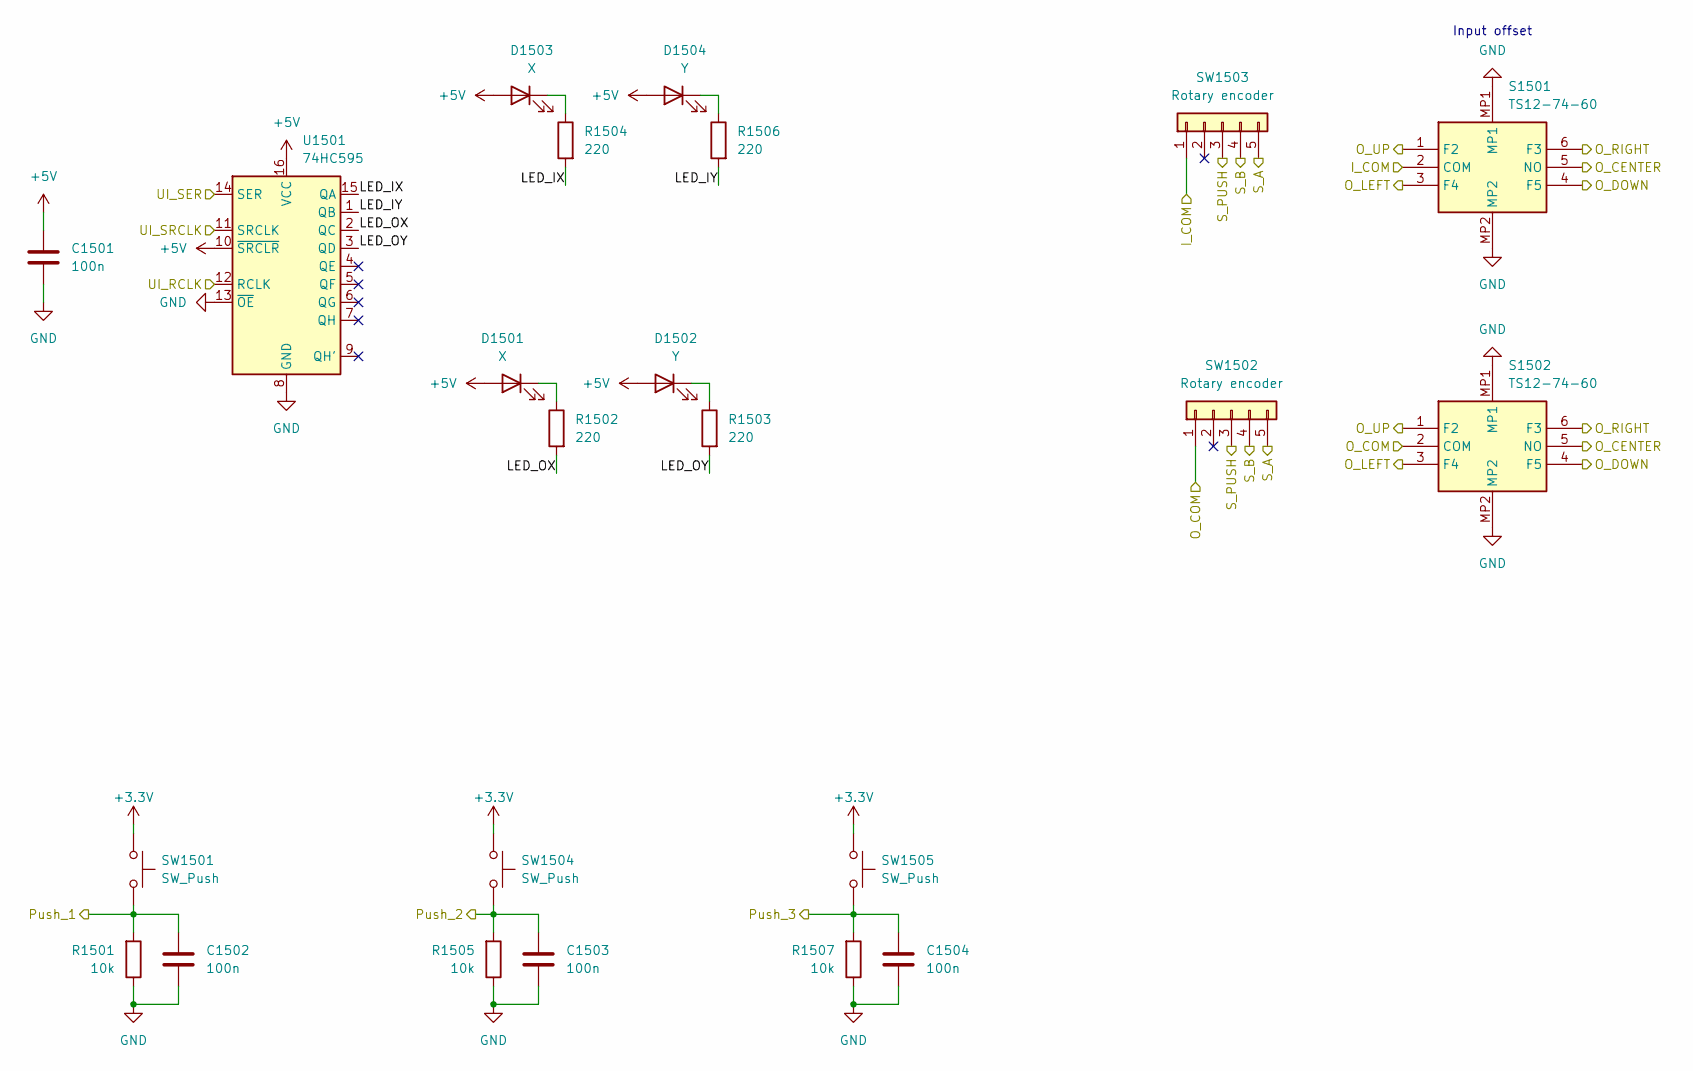
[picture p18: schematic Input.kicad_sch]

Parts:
C1501, C1502, C1503, C1504: 100n; C_0603_1608Metric
D1501, D1503: X; LED_0603_1608Metric
D1502, D1504: Y; LED_0603_1608Metric
R1501, R1505, R1507: 10k; R_0603_1608Metric
R1502, R1503, R1504, R1506: 220; R_0603_1608Metric
S1501, S1502: TS12-74-60; TS127460; Mouser Part Number 179-TS127460250SMTTR
SW1501, SW1504, SW1505: SW_Push; SW_SPST_B3S-1000
SW1502, SW1503: Rotary encoder; Untitled
U1501: 74HC595; DHVQFN-16-1EP_2.5x3.5mm_P0.5mm_EP1x2mm

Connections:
+3.3V: SW1501.1, SW1504.1, SW1505.1; also elsewhere on the board
+5V: C1501.1, D1501.2 (A), D1502.2 (A), D1503.2 (A), D1504.2 (A), U1501.10 (~SRCLR), U1501.16 (VCC); also elsewhere on the board
/Measurement & Control/I_COM: S1501.2 (COM), SW1503.1; also elsewhere on the board
/Measurement & Control/O_CENTER: S1501.5 (NO), S1502.5 (NO); also elsewhere on the board
/Measurement & Control/O_COM: S1502.2 (COM), SW1502.1; also elsewhere on the board
/Measurement & Control/O_DOWN: S1501.4 (F5), S1502.4 (F5); also elsewhere on the board
/Measurement & Control/O_LEFT: S1501.3 (F4), S1502.3 (F4); also elsewhere on the board
/Measurement & Control/O_RIGHT: S1501.6 (F3), S1502.6 (F3); also elsewhere on the board
/Measurement & Control/O_UP: S1501.1 (F2), S1502.1 (F2); also elsewhere on the board
/Measurement & Control/Push_1: C1502.1, R1501.2, SW1501.2; also elsewhere on the board
/Measurement & Control/Push_2: C1503.1, R1505.2, SW1504.2; also elsewhere on the board
/Measurement & Control/Push_3: C1504.1, R1507.2, SW1505.2; also elsewhere on the board
/Measurement & Control/S_A: SW1502.5, SW1503.5; also elsewhere on the board
/Measurement & Control/S_B: SW1502.4, SW1503.4; also elsewhere on the board
/Measurement & Control/S_PUSH: SW1502.3, SW1503.3; also elsewhere on the board
/Measurement & Control/UI_RCLK: U1501.12 (RCLK); also elsewhere on the board
/Measurement & Control/UI_SER: U1501.14 (SER); also elsewhere on the board
/Measurement & Control/UI_SRCLK: U1501.11 (SRCLK); also elsewhere on the board
/User Input/LED_IX: R1504.2, U1501.15 (QA)
/User Input/LED_IY: R1506.2, U1501.1 (QB)
/User Input/LED_OX: R1502.2, U1501.2 (QC)
/User Input/LED_OY: R1503.2, U1501.3 (QD)
GND: C1501.2, C1502.2, C1503.2, C1504.2, R1501.1, R1505.1, R1507.1, S1501.MP1, S1501.MP2, S1502.MP1, S1502.MP2, U1501.8 (GND), U1501.13 (~OE), U1501.17; also elsewhere on the board
unnamed: D1501.1 (K), R1502.1
unnamed: D1502.1 (K), R1503.1
unnamed: D1503.1 (K), R1504.1
unnamed: D1504.1 (K), R1506.1

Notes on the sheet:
Input offset

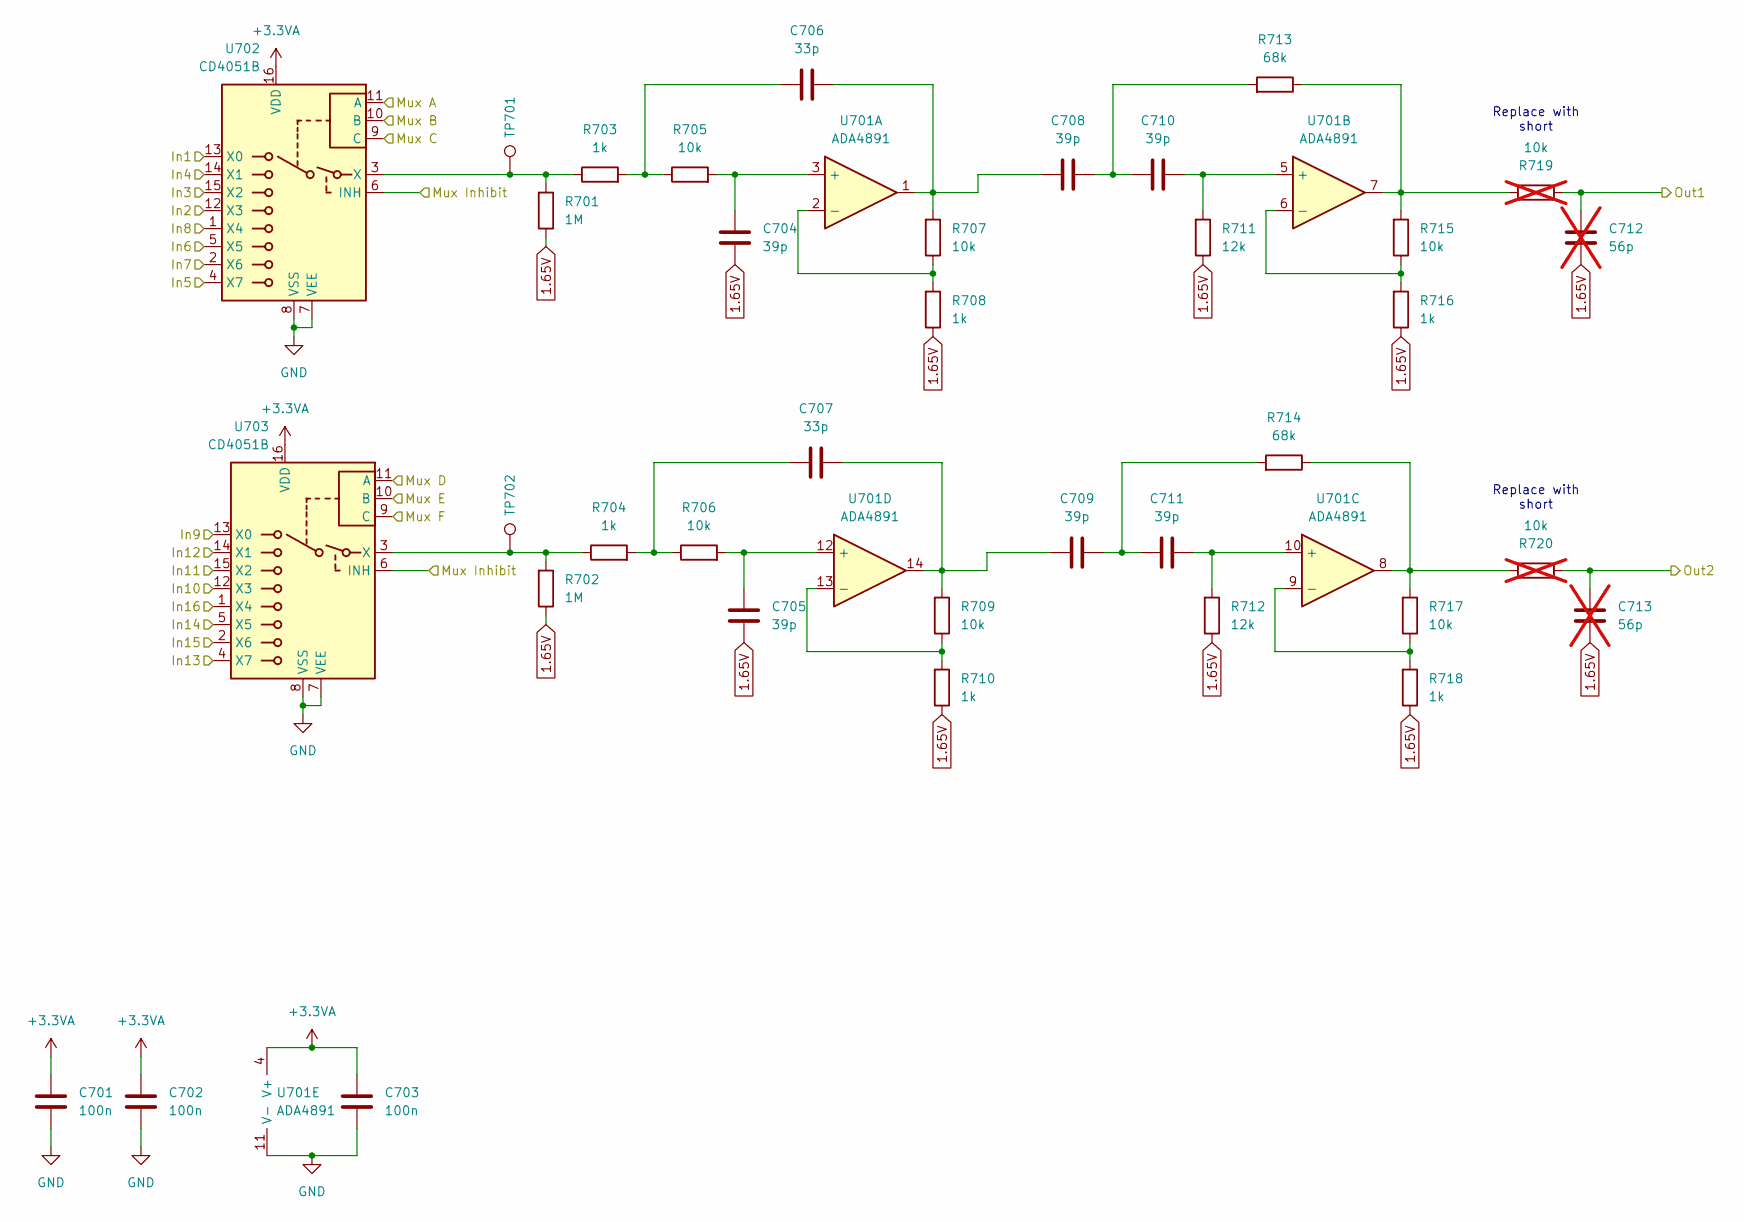
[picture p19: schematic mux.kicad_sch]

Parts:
C701, C702, C703: 100n; C_0603_1608Metric
C704, C705, C708, C709, C710, C711: 39p; C_0603_1608Metric
C706, C707: 33p; C_0603_1608Metric
C712, C713: 56p; C_0603_1608Metric; not fitted
R701, R702: 1M; R_0603_1608Metric
R703, R704, R708, R710, R716, R718: 1k; R_0603_1608Metric
R705, R706, R707, R709, R715, R717: 10k; R_0603_1608Metric
R711, R712: 12k; R_0603_1608Metric
R713, R714: 68k; R_0603_1608Metric
R719, R720: 10k; R_0603_1608Metric; not fitted
TP701, TP702: TestPoint; TestPoint_Pad_1.5x1.5mm
U701: ADA4891; SOIC-14_3.9x8.7mm_P1.27mm
U702, U703: CD4051B; SOIC-16_3.9x9.9mm_P1.27mm

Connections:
1.65V: C704.2, C705.2, C712.1, C713.1, R701.1, R702.1, R708.1, R710.1, R711.1, R712.1, R716.1, R718.1; also elsewhere on the board
+3.3VA: C701.1, C702.1, C703.1, U701.4 (V+), U702.16 (VDD), U703.16 (VDD); also elsewhere on the board
/Measurement & Control/Mux A: U702.11 (A), U703.11 (A); also elsewhere on the board
/Measurement & Control/Mux B: U702.10 (B), U703.10 (B); also elsewhere on the board
/Measurement & Control/Mux C: U702.9 (C), U703.9 (C); also elsewhere on the board
/Measurement & Control/Mux Inhibit: U702.6 (INH), U703.6 (INH); also elsewhere on the board
/Measurement & Control/Rx1: C712.2, R719.1; also elsewhere on the board
/Measurement & Control/Rx2: C713.2, R720.1; also elsewhere on the board
/Mux & Amplifier 1/In1: U702.13 (X0); also elsewhere on the board
/Mux & Amplifier 1/In2: U702.12 (X3); also elsewhere on the board
/Mux & Amplifier 1/In3: U702.15 (X2); also elsewhere on the board
/Mux & Amplifier 1/In4: U702.14 (X1); also elsewhere on the board
/Mux & Amplifier 1/In5: U702.4 (X7); also elsewhere on the board
/Mux & Amplifier 1/In6: U702.5 (X5); also elsewhere on the board
/Mux & Amplifier 1/In7: U702.2 (X6); also elsewhere on the board
/Mux & Amplifier 1/In8: U702.1 (X4); also elsewhere on the board
/Mux & Amplifier 1/In9: U703.13 (X0); also elsewhere on the board
/Mux & Amplifier 1/In10: U703.12 (X3); also elsewhere on the board
/Mux & Amplifier 1/In11: U703.15 (X2); also elsewhere on the board
/Mux & Amplifier 1/In12: U703.14 (X1); also elsewhere on the board
/Mux & Amplifier 1/In13: U703.4 (X7); also elsewhere on the board
/Mux & Amplifier 1/In14: U703.5 (X5); also elsewhere on the board
/Mux & Amplifier 1/In15: U703.2 (X6); also elsewhere on the board
/Mux & Amplifier 1/In16: U703.1 (X4); also elsewhere on the board
GND: C701.2, C702.2, C703.2, U701.11 (V-), U702.7 (VEE), U702.8 (VSS), U703.7 (VEE), U703.8 (VSS); also elsewhere on the board
unnamed: C706.1, R703.2, R705.1
unnamed: C706.2, C708.1, R707.2, U701.1
unnamed: C707.1, R704.2, R706.1
unnamed: C707.2, C709.1, R709.2, U701.14
unnamed: C708.2, C710.1, R713.2
unnamed: C709.2, C711.1, R714.2
unnamed: R713.1, R715.2, R719.2, U701.7
unnamed: R714.1, R717.2, R720.2, U701.8
unnamed: C704.1, R705.2, U701.3 (+)
unnamed: R707.1, R708.2, U701.2 (-)
unnamed: C710.2, R711.2, U701.5 (+)
unnamed: R715.1, R716.2, U701.6 (-)
unnamed: C711.2, R712.2, U701.10 (+)
unnamed: R717.1, R718.2, U701.9 (-)
unnamed: C705.1, R706.2, U701.12 (+)
unnamed: R709.1, R710.2, U701.13 (-)
unnamed: R701.2, R703.1, TP701.1, U702.3 (X)
unnamed: R702.2, R704.1, TP702.1, U703.3 (X)

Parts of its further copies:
C801, C802, C803: 100n; C_0603_1608Metric
C804, C805, C808, C809, C810, C811: 39p; C_0603_1608Metric
C806, C807: 33p; C_0603_1608Metric
C812, C813: 56p; C_0603_1608Metric; not fitted
R801, R802: 1M; R_0603_1608Metric
R803, R804, R808, R810, R816, R818: 1k; R_0603_1608Metric
R805, R806, R807, R809, R815, R817: 10k; R_0603_1608Metric
R811, R812: 12k; R_0603_1608Metric
R813, R814: 68k; R_0603_1608Metric
R819, R820: 10k; R_0603_1608Metric; not fitted
TP801, TP802: TestPoint; TestPoint_Pad_1.5x1.5mm
U801: ADA4891; SOIC-14_3.9x8.7mm_P1.27mm
U802, U803: CD4051B; SOIC-16_3.9x9.9mm_P1.27mm

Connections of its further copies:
1.65V: C804.2, C805.2, C812.1, C813.1, R801.1, R802.1, R808.1, R810.1, R811.1, R812.1, R816.1, R818.1; also elsewhere on the board
+3.3VA: C801.1, C802.1, C803.1, U801.4 (V+), U802.16 (VDD), U803.16 (VDD); also elsewhere on the board
/Measurement & Control/Mux A: U802.11 (A), U803.11 (A); also elsewhere on the board
/Measurement & Control/Mux B: U802.10 (B), U803.10 (B); also elsewhere on the board
/Measurement & Control/Mux C: U802.9 (C), U803.9 (C); also elsewhere on the board
/Measurement & Control/Mux Inhibit: U802.6 (INH), U803.6 (INH); also elsewhere on the board
/Measurement & Control/Rx3: C812.2, R819.1; also elsewhere on the board
/Measurement & Control/Rx4: C813.2, R820.1; also elsewhere on the board
/Mux & Amplifier 2/In1: U802.13 (X0); also elsewhere on the board
/Mux & Amplifier 2/In2: U802.12 (X3); also elsewhere on the board
/Mux & Amplifier 2/In3: U802.15 (X2); also elsewhere on the board
/Mux & Amplifier 2/In4: U802.14 (X1); also elsewhere on the board
/Mux & Amplifier 2/In5: U802.4 (X7); also elsewhere on the board
/Mux & Amplifier 2/In6: U802.5 (X5); also elsewhere on the board
/Mux & Amplifier 2/In7: U802.2 (X6); also elsewhere on the board
/Mux & Amplifier 2/In8: U802.1 (X4); also elsewhere on the board
/Mux & Amplifier 2/In9: U803.13 (X0); also elsewhere on the board
/Mux & Amplifier 2/In10: U803.12 (X3); also elsewhere on the board
/Mux & Amplifier 2/In11: U803.15 (X2); also elsewhere on the board
/Mux & Amplifier 2/In12: U803.14 (X1); also elsewhere on the board
/Mux & Amplifier 2/In13: U803.4 (X7); also elsewhere on the board
/Mux & Amplifier 2/In14: U803.5 (X5); also elsewhere on the board
/Mux & Amplifier 2/In15: U803.2 (X6); also elsewhere on the board
/Mux & Amplifier 2/In16: U803.1 (X4); also elsewhere on the board
GND: C801.2, C802.2, C803.2, U801.11 (V-), U802.7 (VEE), U802.8 (VSS), U803.7 (VEE), U803.8 (VSS); also elsewhere on the board
unnamed: C806.1, R803.2, R805.1
unnamed: C806.2, C808.1, R807.2, U801.1
unnamed: C807.1, R804.2, R806.1
unnamed: C807.2, C809.1, R809.2, U801.14
unnamed: C808.2, C810.1, R813.2
unnamed: C809.2, C811.1, R814.2
unnamed: R813.1, R815.2, R819.2, U801.7
unnamed: R814.1, R817.2, R820.2, U801.8
unnamed: C804.1, R805.2, U801.3 (+)
unnamed: R807.1, R808.2, U801.2 (-)
unnamed: C810.2, R811.2, U801.5 (+)
unnamed: R815.1, R816.2, U801.6 (-)
unnamed: C811.2, R812.2, U801.10 (+)
unnamed: R817.1, R818.2, U801.9 (-)
unnamed: C805.1, R806.2, U801.12 (+)
unnamed: R809.1, R810.2, U801.13 (-)
unnamed: R801.2, R803.1, TP801.1, U802.3 (X)
unnamed: R802.2, R804.1, TP802.1, U803.3 (X)

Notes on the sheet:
Replace with short

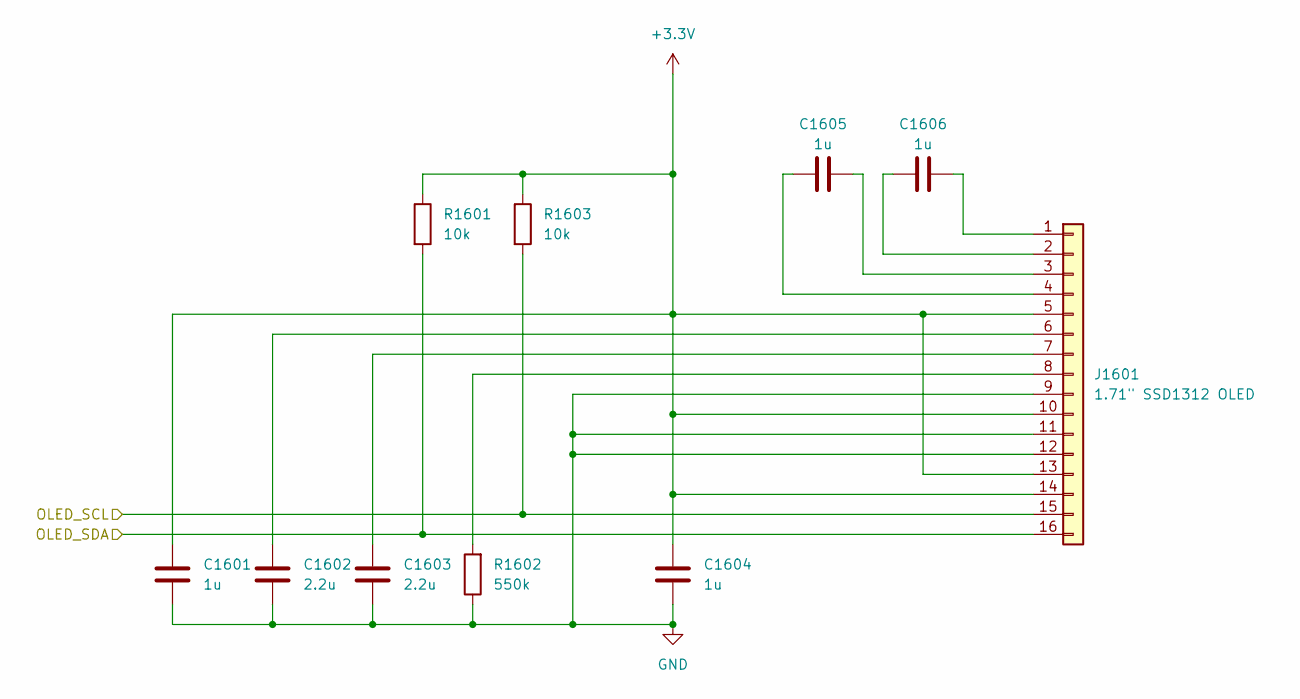
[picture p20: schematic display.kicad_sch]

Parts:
C1601, C1604: 1u; C_0603_1608Metric
C1602, C1603: 2.2u; C_0603_1608Metric
C1605, C1606: 1u; C_0603_1608Metric; Rating 10V
J1601: 1.71" SSD1312 OLED; 1.71 OLED SSD1312
R1601, R1603: 10k; R_0603_1608Metric
R1602: 550k; R_0603_1608Metric

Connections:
+3.3V: C1601.1, C1604.1, J1601.5, J1601.10, J1601.13, J1601.14, R1601.1, R1603.1; also elsewhere on the board
/Measurement & Control/OLED_SCL: J1601.15, R1603.2; also elsewhere on the board
/Measurement & Control/OLED_SDA: J1601.16, R1601.2; also elsewhere on the board
GND: C1601.2, C1602.2, C1603.2, C1604.2, J1601.9, J1601.11, J1601.12, R1602.1; also elsewhere on the board
unnamed: C1606.2, J1601.1
unnamed: C1606.1, J1601.2
unnamed: C1605.2, J1601.3
unnamed: C1605.1, J1601.4
unnamed: C1602.1, J1601.6
unnamed: C1603.1, J1601.7
unnamed: J1601.8, R1602.2

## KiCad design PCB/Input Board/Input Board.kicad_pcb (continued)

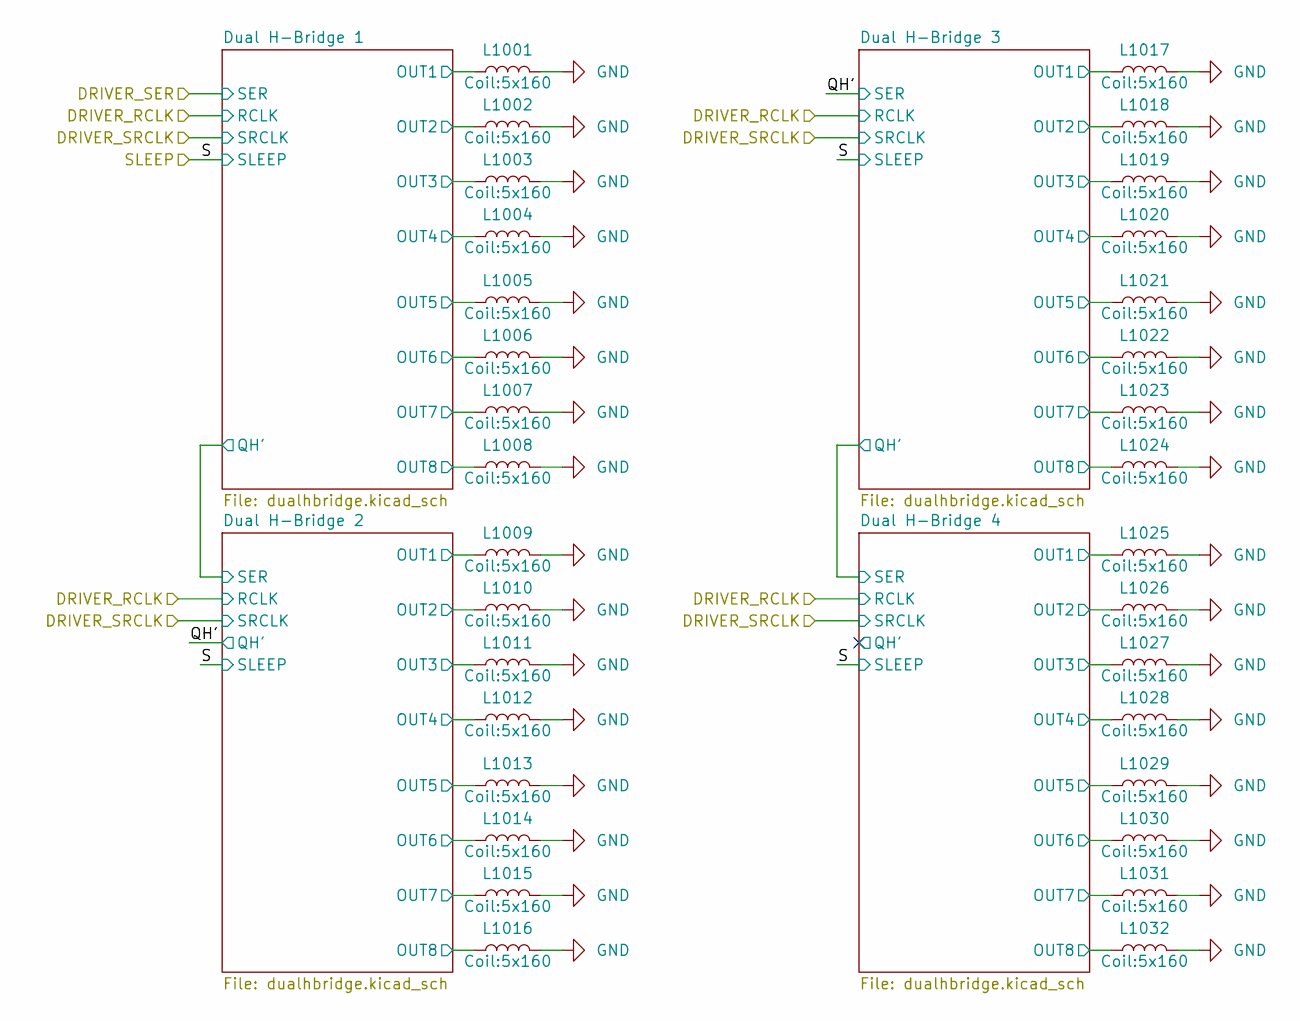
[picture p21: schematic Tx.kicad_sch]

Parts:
L1001, L1002, L1003, L1004, L1005, L1006, L1007, L1008, L1009, L1010, L1011, L1012, L1013, L1014, L1015, L1016, L1017, L1018, L1019, L1020, L1021, L1022, L1023, L1024, L1025, L1026, L1027, L1028, L1029, L1030, L1031, L1032: L; 5x160

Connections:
/Transmit Coils/Dual H-Bridge 1/OUT1: L1001.1; also elsewhere on the board
/Transmit Coils/Dual H-Bridge 1/OUT2: L1002.1; also elsewhere on the board
/Transmit Coils/Dual H-Bridge 1/OUT3: L1003.1; also elsewhere on the board
/Transmit Coils/Dual H-Bridge 1/OUT4: L1004.1; also elsewhere on the board
/Transmit Coils/Dual H-Bridge 1/OUT5: L1005.1; also elsewhere on the board
/Transmit Coils/Dual H-Bridge 1/OUT6: L1006.1; also elsewhere on the board
/Transmit Coils/Dual H-Bridge 1/OUT7: L1007.1; also elsewhere on the board
/Transmit Coils/Dual H-Bridge 1/OUT8: L1008.1; also elsewhere on the board
/Transmit Coils/Dual H-Bridge 2/OUT1: L1009.1; also elsewhere on the board
/Transmit Coils/Dual H-Bridge 2/OUT2: L1010.1; also elsewhere on the board
/Transmit Coils/Dual H-Bridge 2/OUT3: L1011.1; also elsewhere on the board
/Transmit Coils/Dual H-Bridge 2/OUT4: L1012.1; also elsewhere on the board
/Transmit Coils/Dual H-Bridge 2/OUT5: L1013.1; also elsewhere on the board
/Transmit Coils/Dual H-Bridge 2/OUT6: L1014.1; also elsewhere on the board
/Transmit Coils/Dual H-Bridge 2/OUT7: L1015.1; also elsewhere on the board
/Transmit Coils/Dual H-Bridge 2/OUT8: L1016.1; also elsewhere on the board
/Transmit Coils/Dual H-Bridge 3/OUT1: L1017.1; also elsewhere on the board
/Transmit Coils/Dual H-Bridge 3/OUT2: L1018.1; also elsewhere on the board
/Transmit Coils/Dual H-Bridge 3/OUT3: L1019.1; also elsewhere on the board
/Transmit Coils/Dual H-Bridge 3/OUT4: L1020.1; also elsewhere on the board
/Transmit Coils/Dual H-Bridge 3/OUT5: L1021.1; also elsewhere on the board
/Transmit Coils/Dual H-Bridge 3/OUT6: L1022.1; also elsewhere on the board
/Transmit Coils/Dual H-Bridge 3/OUT7: L1023.1; also elsewhere on the board
/Transmit Coils/Dual H-Bridge 3/OUT8: L1024.1; also elsewhere on the board
/Transmit Coils/Dual H-Bridge 4/OUT1: L1025.1; also elsewhere on the board
/Transmit Coils/Dual H-Bridge 4/OUT2: L1026.1; also elsewhere on the board
/Transmit Coils/Dual H-Bridge 4/OUT3: L1027.1; also elsewhere on the board
/Transmit Coils/Dual H-Bridge 4/OUT4: L1028.1; also elsewhere on the board
/Transmit Coils/Dual H-Bridge 4/OUT5: L1029.1; also elsewhere on the board
/Transmit Coils/Dual H-Bridge 4/OUT6: L1030.1; also elsewhere on the board
/Transmit Coils/Dual H-Bridge 4/OUT7: L1031.1; also elsewhere on the board
/Transmit Coils/Dual H-Bridge 4/OUT8: L1032.1; also elsewhere on the board
GND: L1001.2, L1002.2, L1003.2, L1004.2, L1005.2, L1006.2, L1007.2, L1008.2, L1009.2, L1010.2, L1011.2, L1012.2, L1013.2, L1014.2, L1015.2, L1016.2, L1017.2, L1018.2, L1019.2, L1020.2, L1021.2, L1022.2, L1023.2, L1024.2, L1025.2, L1026.2, L1027.2, L1028.2, L1029.2, L1030.2, L1031.2, L1032.2; also elsewhere on the board

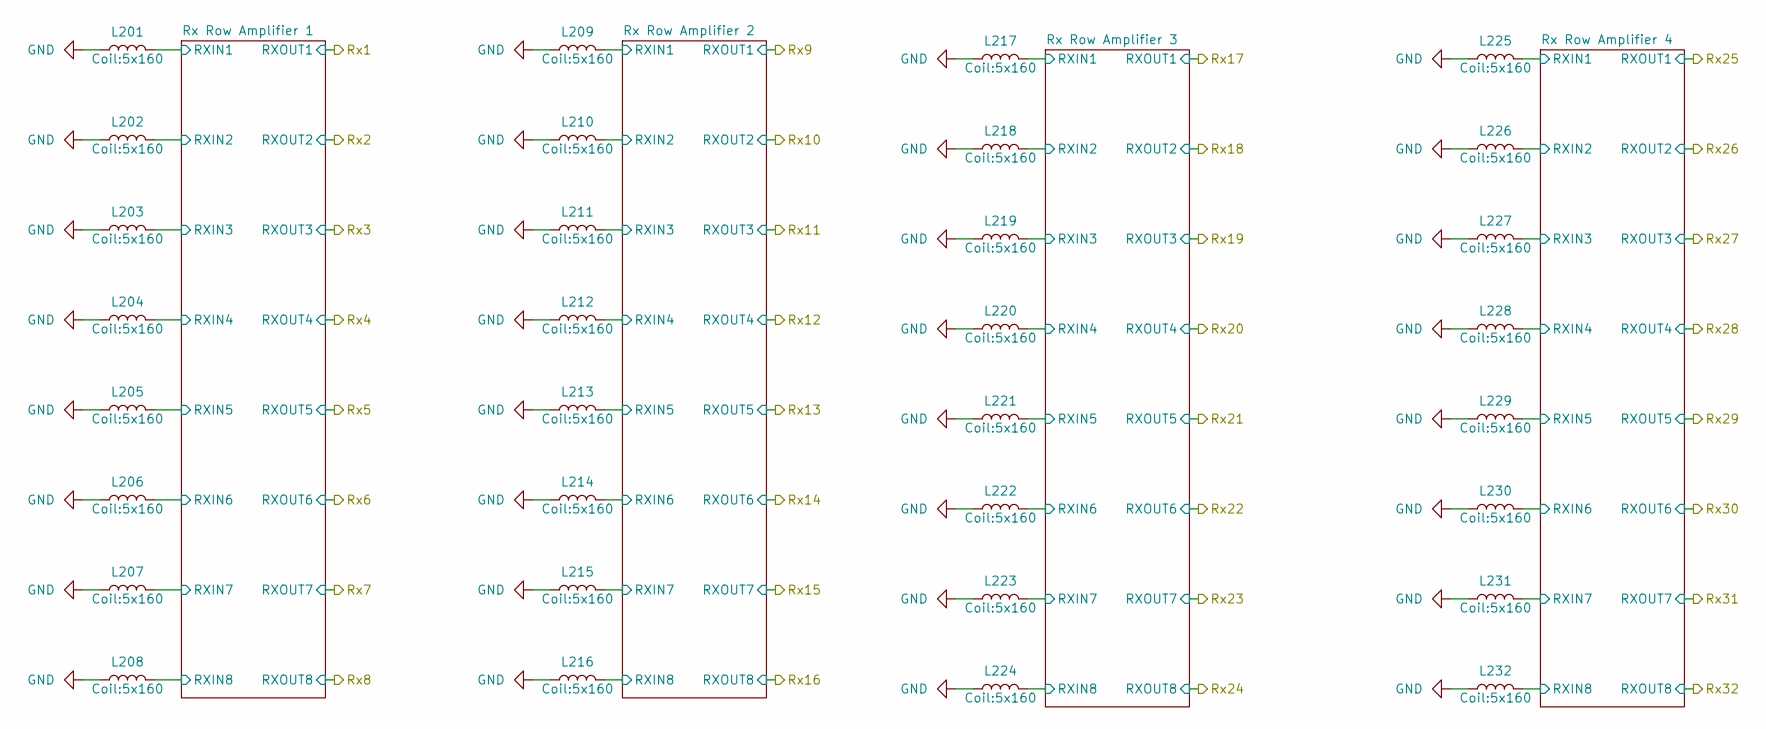
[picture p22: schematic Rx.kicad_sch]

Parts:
L201, L202, L203, L204, L205, L206, L207, L208, L209, L210, L211, L212, L213, L214, L215, L216, L217, L218, L219, L220, L221, L222, L223, L224, L225, L226, L227, L228, L229, L230, L231, L232: L; 5x160

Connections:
/Receiver Stage/Rx Row Amplifier 1/RXIN1: L201.2; also elsewhere on the board
/Receiver Stage/Rx Row Amplifier 1/RXIN2: L202.2; also elsewhere on the board
/Receiver Stage/Rx Row Amplifier 1/RXIN3: L203.2; also elsewhere on the board
/Receiver Stage/Rx Row Amplifier 1/RXIN4: L204.2; also elsewhere on the board
/Receiver Stage/Rx Row Amplifier 1/RXIN5: L205.2; also elsewhere on the board
/Receiver Stage/Rx Row Amplifier 1/RXIN6: L206.2; also elsewhere on the board
/Receiver Stage/Rx Row Amplifier 1/RXIN7: L207.2; also elsewhere on the board
/Receiver Stage/Rx Row Amplifier 1/RXIN8: L208.2; also elsewhere on the board
/Receiver Stage/Rx Row Amplifier 2/RXIN1: L209.2; also elsewhere on the board
/Receiver Stage/Rx Row Amplifier 2/RXIN2: L210.2; also elsewhere on the board
/Receiver Stage/Rx Row Amplifier 2/RXIN3: L211.2; also elsewhere on the board
/Receiver Stage/Rx Row Amplifier 2/RXIN4: L212.2; also elsewhere on the board
/Receiver Stage/Rx Row Amplifier 2/RXIN5: L213.2; also elsewhere on the board
/Receiver Stage/Rx Row Amplifier 2/RXIN6: L214.2; also elsewhere on the board
/Receiver Stage/Rx Row Amplifier 2/RXIN7: L215.2; also elsewhere on the board
/Receiver Stage/Rx Row Amplifier 2/RXIN8: L216.2; also elsewhere on the board
/Receiver Stage/Rx Row Amplifier 3/RXIN1: L217.2; also elsewhere on the board
/Receiver Stage/Rx Row Amplifier 3/RXIN2: L218.2; also elsewhere on the board
/Receiver Stage/Rx Row Amplifier 3/RXIN3: L219.2; also elsewhere on the board
/Receiver Stage/Rx Row Amplifier 3/RXIN4: L220.2; also elsewhere on the board
/Receiver Stage/Rx Row Amplifier 3/RXIN5: L221.2; also elsewhere on the board
/Receiver Stage/Rx Row Amplifier 3/RXIN6: L222.2; also elsewhere on the board
/Receiver Stage/Rx Row Amplifier 3/RXIN7: L223.2; also elsewhere on the board
/Receiver Stage/Rx Row Amplifier 3/RXIN8: L224.2; also elsewhere on the board
/Receiver Stage/Rx Row Amplifier 4/RXIN1: L225.2; also elsewhere on the board
/Receiver Stage/Rx Row Amplifier 4/RXIN2: L226.2; also elsewhere on the board
/Receiver Stage/Rx Row Amplifier 4/RXIN3: L227.2; also elsewhere on the board
/Receiver Stage/Rx Row Amplifier 4/RXIN4: L228.2; also elsewhere on the board
/Receiver Stage/Rx Row Amplifier 4/RXIN5: L229.2; also elsewhere on the board
/Receiver Stage/Rx Row Amplifier 4/RXIN6: L230.2; also elsewhere on the board
/Receiver Stage/Rx Row Amplifier 4/RXIN7: L231.2; also elsewhere on the board
/Receiver Stage/Rx Row Amplifier 4/RXIN8: L232.2; also elsewhere on the board
GND: L201.1, L202.1, L203.1, L204.1, L205.1, L206.1, L207.1, L208.1, L209.1, L210.1, L211.1, L212.1, L213.1, L214.1, L215.1, L216.1, L217.1, L218.1, L219.1, L220.1, L221.1, L222.1, L223.1, L224.1, L225.1, L226.1, L227.1, L228.1, L229.1, L230.1, L231.1, L232.1; also elsewhere on the board

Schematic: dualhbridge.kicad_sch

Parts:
C1101, C1102, C1103, C1104, C1105: 100n; C_0603_1608Metric
U1101: 74HCS95; DHVQFN-16-1EP_2.5x3.5mm_P0.5mm_EP1x2mm
U1102, U1103, U1104, U1105: DRV8837; WSON-8-1EP_2x2mm_P0.5mm_EP0.9x1.6mm

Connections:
+5V: C1101.2, C1102.2, C1103.2, C1104.2, C1105.2, U1101.10 (~SRCLR), U1101.16 (VCC), U1102.1 (VM), U1102.8 (VCC), U1103.1 (VM), U1103.8 (VCC), U1104.1 (VM), U1104.8 (VCC), U1105.1 (VM), U1105.8 (VCC); also elsewhere on the board
/Measurement & Control/TX_RCLK: U1101.12 (RCLK); also elsewhere on the board
/Measurement & Control/TX_SDO: U1101.14 (SER); also elsewhere on the board
/Measurement & Control/TX_SLEEP: U1102.7 (~SLEEP), U1103.7 (~SLEEP), U1104.7 (~SLEEP), U1105.7 (~SLEEP); also elsewhere on the board
/Measurement & Control/TX_SRCLK: U1101.11 (SRCLK); also elsewhere on the board
/Transmit Coils/Dual H-Bridge 1/OUT1: U1102.2 (OUT1); also elsewhere on the board
/Transmit Coils/Dual H-Bridge 1/OUT2: U1102.3 (OUT2); also elsewhere on the board
/Transmit Coils/Dual H-Bridge 1/OUT3: U1103.2 (OUT1); also elsewhere on the board
/Transmit Coils/Dual H-Bridge 1/OUT4: U1103.3 (OUT2); also elsewhere on the board
/Transmit Coils/Dual H-Bridge 1/OUT5: U1104.2 (OUT1); also elsewhere on the board
/Transmit Coils/Dual H-Bridge 1/OUT6: U1104.3 (OUT2); also elsewhere on the board
/Transmit Coils/Dual H-Bridge 1/OUT7: U1105.2 (OUT1); also elsewhere on the board
/Transmit Coils/Dual H-Bridge 1/OUT8: U1105.3 (OUT2); also elsewhere on the board
/Transmit Coils/Dual H-Bridge 1/QH': U1101.9 (QH'); also elsewhere on the board
GND: C1101.1, C1102.1, C1103.1, C1104.1, C1105.1, U1101.8 (GND), U1101.13 (~OE), U1101.17, U1102.4 (GND), U1102.9 (GND), U1103.4 (GND), U1103.9 (GND), U1104.4 (GND), U1104.9 (GND), U1105.4 (GND), U1105.9 (GND); also elsewhere on the board
unnamed: U1101.15 (QA), U1102.6 (IN1)
unnamed: U1101.1 (QB), U1102.5 (IN2)
unnamed: U1101.2 (QC), U1103.6 (IN1)
unnamed: U1101.3 (QD), U1103.5 (IN2)
unnamed: U1101.4 (QE), U1104.6 (IN1)
unnamed: U1101.5 (QF), U1104.5 (IN2)
unnamed: U1101.6 (QG), U1105.6 (IN1)
unnamed: U1101.7 (QH), U1105.5 (IN2)

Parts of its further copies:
C1201, C1202, C1203, C1204, C1205, C1301, C1302, C1303, C1304, C1305, C1401, C1402, C1403, C1404, C1405: 100n; C_0603_1608Metric
U1201, U1301, U1401: 74HCS95; DHVQFN-16-1EP_2.5x3.5mm_P0.5mm_EP1x2mm
U1202, U1203, U1204, U1205, U1302, U1303, U1304, U1305, U1402, U1403, U1404, U1405: DRV8837; WSON-8-1EP_2x2mm_P0.5mm_EP0.9x1.6mm

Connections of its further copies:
+5V: C1201.2, C1202.2, C1203.2, C1204.2, C1205.2, C1301.2, C1302.2, C1303.2, C1304.2, C1305.2, C1401.2, C1402.2, C1403.2, C1404.2, C1405.2, U1201.10 (~SRCLR), U1201.16 (VCC), U1202.1 (VM), U1202.8 (VCC), U1203.1 (VM), U1203.8 (VCC), U1204.1 (VM), U1204.8 (VCC), U1205.1 (VM), U1205.8 (VCC), U1301.10 (~SRCLR), U1301.16 (VCC), U1302.1 (VM), U1302.8 (VCC), U1303.1 (VM), U1303.8 (VCC), U1304.1 (VM), U1304.8 (VCC), U1305.1 (VM), U1305.8 (VCC), U1401.10 (~SRCLR), U1401.16 (VCC), U1402.1 (VM), U1402.8 (VCC), U1403.1 (VM), U1403.8 (VCC), U1404.1 (VM), U1404.8 (VCC), U1405.1 (VM), U1405.8 (VCC); also elsewhere on the board
/Measurement & Control/TX_RCLK: U1201.12 (RCLK), U1301.12 (RCLK), U1401.12 (RCLK); also elsewhere on the board
/Measurement & Control/TX_SLEEP: U1202.7 (~SLEEP), U1203.7 (~SLEEP), U1204.7 (~SLEEP), U1205.7 (~SLEEP), U1302.7 (~SLEEP), U1303.7 (~SLEEP), U1304.7 (~SLEEP), U1305.7 (~SLEEP), U1402.7 (~SLEEP), U1403.7 (~SLEEP), U1404.7 (~SLEEP), U1405.7 (~SLEEP); also elsewhere on the board
/Measurement & Control/TX_SRCLK: U1201.11 (SRCLK), U1301.11 (SRCLK), U1401.11 (SRCLK); also elsewhere on the board
/Transmit Coils/Dual H-Bridge 1/QH': U1201.14 (SER); also elsewhere on the board
/Transmit Coils/Dual H-Bridge 2/OUT1: U1202.2 (OUT1); also elsewhere on the board
/Transmit Coils/Dual H-Bridge 2/OUT2: U1202.3 (OUT2); also elsewhere on the board
/Transmit Coils/Dual H-Bridge 2/OUT3: U1203.2 (OUT1); also elsewhere on the board
/Transmit Coils/Dual H-Bridge 2/OUT4: U1203.3 (OUT2); also elsewhere on the board
/Transmit Coils/Dual H-Bridge 2/OUT5: U1204.2 (OUT1); also elsewhere on the board
/Transmit Coils/Dual H-Bridge 2/OUT6: U1204.3 (OUT2); also elsewhere on the board
/Transmit Coils/Dual H-Bridge 2/OUT7: U1205.2 (OUT1); also elsewhere on the board
/Transmit Coils/Dual H-Bridge 2/OUT8: U1205.3 (OUT2); also elsewhere on the board
/Transmit Coils/Dual H-Bridge 3/OUT1: U1302.2 (OUT1); also elsewhere on the board
/Transmit Coils/Dual H-Bridge 3/OUT2: U1302.3 (OUT2); also elsewhere on the board
/Transmit Coils/Dual H-Bridge 3/OUT3: U1303.2 (OUT1); also elsewhere on the board
/Transmit Coils/Dual H-Bridge 3/OUT4: U1303.3 (OUT2); also elsewhere on the board
/Transmit Coils/Dual H-Bridge 3/OUT5: U1304.2 (OUT1); also elsewhere on the board
/Transmit Coils/Dual H-Bridge 3/OUT6: U1304.3 (OUT2); also elsewhere on the board
/Transmit Coils/Dual H-Bridge 3/OUT7: U1305.2 (OUT1); also elsewhere on the board
/Transmit Coils/Dual H-Bridge 3/OUT8: U1305.3 (OUT2); also elsewhere on the board
/Transmit Coils/Dual H-Bridge 3/QH': U1301.9 (QH'), U1401.14 (SER)
/Transmit Coils/Dual H-Bridge 4/OUT1: U1402.2 (OUT1); also elsewhere on the board
/Transmit Coils/Dual H-Bridge 4/OUT2: U1402.3 (OUT2); also elsewhere on the board
/Transmit Coils/Dual H-Bridge 4/OUT3: U1403.2 (OUT1); also elsewhere on the board
/Transmit Coils/Dual H-Bridge 4/OUT4: U1403.3 (OUT2); also elsewhere on the board
/Transmit Coils/Dual H-Bridge 4/OUT5: U1404.2 (OUT1); also elsewhere on the board
/Transmit Coils/Dual H-Bridge 4/OUT6: U1404.3 (OUT2); also elsewhere on the board
/Transmit Coils/Dual H-Bridge 4/OUT7: U1405.2 (OUT1); also elsewhere on the board
/Transmit Coils/Dual H-Bridge 4/OUT8: U1405.3 (OUT2); also elsewhere on the board
/Transmit Coils/Dual H-Bridge 4/QH&apos;: U1401.9 (QH')
/Transmit Coils/QH': U1201.9 (QH'), U1301.14 (SER)
GND: C1201.1, C1202.1, C1203.1, C1204.1, C1205.1, C1301.1, C1302.1, C1303.1, C1304.1, C1305.1, C1401.1, C1402.1, C1403.1, C1404.1, C1405.1, U1201.8 (GND), U1201.13 (~OE), U1201.17, U1202.4 (GND), U1202.9 (GND), U1203.4 (GND), U1203.9 (GND), U1204.4 (GND), U1204.9 (GND), U1205.4 (GND), U1205.9 (GND), U1301.8 (GND), U1301.13 (~OE), U1301.17, U1302.4 (GND), U1302.9 (GND), U1303.4 (GND), U1303.9 (GND), U1304.4 (GND), U1304.9 (GND), U1305.4 (GND), U1305.9 (GND), U1401.8 (GND), U1401.13 (~OE), U1401.17, U1402.4 (GND), U1402.9 (GND), U1403.4 (GND), U1403.9 (GND), U1404.4 (GND), U1404.9 (GND), U1405.4 (GND), U1405.9 (GND); also elsewhere on the board
unnamed: U1201.15 (QA), U1202.6 (IN1)
unnamed: U1201.1 (QB), U1202.5 (IN2)
unnamed: U1201.2 (QC), U1203.6 (IN1)
unnamed: U1201.3 (QD), U1203.5 (IN2)
unnamed: U1201.4 (QE), U1204.6 (IN1)
unnamed: U1201.5 (QF), U1204.5 (IN2)
unnamed: U1201.6 (QG), U1205.6 (IN1)
unnamed: U1201.7 (QH), U1205.5 (IN2)
unnamed: U1301.15 (QA), U1302.6 (IN1)
unnamed: U1301.1 (QB), U1302.5 (IN2)
unnamed: U1301.2 (QC), U1303.6 (IN1)
unnamed: U1301.3 (QD), U1303.5 (IN2)
unnamed: U1301.4 (QE), U1304.6 (IN1)
unnamed: U1301.5 (QF), U1304.5 (IN2)
unnamed: U1301.6 (QG), U1305.6 (IN1)
unnamed: U1301.7 (QH), U1305.5 (IN2)
unnamed: U1401.15 (QA), U1402.6 (IN1)
unnamed: U1401.1 (QB), U1402.5 (IN2)
unnamed: U1401.2 (QC), U1403.6 (IN1)
unnamed: U1401.3 (QD), U1403.5 (IN2)
unnamed: U1401.4 (QE), U1404.6 (IN1)
unnamed: U1401.5 (QF), U1404.5 (IN2)
unnamed: U1401.6 (QG), U1405.6 (IN1)
unnamed: U1401.7 (QH), U1405.5 (IN2)

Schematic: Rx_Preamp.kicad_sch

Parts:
C301, C302, C303, C304, C306, C307, C309, C310, C311, C312, C313, C314, C315, C316, C317, C318: 1.8n; C_0603_1608Metric
C305, C308: 100n; C_0603_1608Metric
R301, R302, R303, R304, R307, R308, R309, R310, R313, R314, R315, R316, R319, R320, R321, R322: 1k; R_0603_1608Metric
R305, R306, R311, R312, R317, R318, R323, R324: 15k; R_0603_1608Metric
U301, U302: TSV994; SOIC-14_3.9x8.7mm_P1.27mm

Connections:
1.65V: C303.2, C304.2, C309.2, C310.2, C313.2, C314.2, C317.2, C318.2, R301.1, R302.1, R307.1, R308.1, R313.1, R314.1, R319.1, R320.1; also elsewhere on the board
+3.3VA: C305.1, C308.1, U301.4 (V+), U302.4 (V+); also elsewhere on the board
/Mux & Amplifier 1/In1: R305.2, U301.1; also elsewhere on the board
/Mux & Amplifier 1/In2: R306.2, U301.7; also elsewhere on the board
/Mux & Amplifier 1/In3: R311.2, U301.8; also elsewhere on the board
/Mux & Amplifier 1/In4: R312.2, U301.14; also elsewhere on the board
/Mux & Amplifier 1/In5: R317.2, U302.1; also elsewhere on the board
/Mux & Amplifier 1/In6: R318.2, U302.7; also elsewhere on the board
/Mux & Amplifier 1/In7: R323.2, U302.8; also elsewhere on the board
/Mux & Amplifier 1/In8: R324.2, U302.14; also elsewhere on the board
/Receiver Stage/Rx Row Amplifier 1/RXIN1: C301.2; also elsewhere on the board
/Receiver Stage/Rx Row Amplifier 1/RXIN2: C302.2; also elsewhere on the board
/Receiver Stage/Rx Row Amplifier 1/RXIN3: C306.2; also elsewhere on the board
/Receiver Stage/Rx Row Amplifier 1/RXIN4: C307.2; also elsewhere on the board
/Receiver Stage/Rx Row Amplifier 1/RXIN5: C311.2; also elsewhere on the board
/Receiver Stage/Rx Row Amplifier 1/RXIN6: C312.2; also elsewhere on the board
/Receiver Stage/Rx Row Amplifier 1/RXIN7: C315.2; also elsewhere on the board
/Receiver Stage/Rx Row Amplifier 1/RXIN8: C316.2; also elsewhere on the board
GND: C305.2, C308.2, U301.11 (V-), U302.11 (V-); also elsewhere on the board
unnamed: C303.1, R303.2
unnamed: C304.1, R304.2
unnamed: C309.1, R309.2
unnamed: C310.1, R310.2
unnamed: C313.1, R315.2
unnamed: C314.1, R316.2
unnamed: C317.1, R321.2
unnamed: C318.1, R322.2
unnamed: C301.1, R301.2, U301.3 (+)
unnamed: R303.1, R305.1, U301.2 (-)
unnamed: C302.1, R302.2, U301.5 (+)
unnamed: R304.1, R306.1, U301.6 (-)
unnamed: C306.1, R307.2, U301.10 (+)
unnamed: R309.1, R311.1, U301.9 (-)
unnamed: C307.1, R308.2, U301.12 (+)
unnamed: R310.1, R312.1, U301.13 (-)
unnamed: C311.1, R313.2, U302.3 (+)
unnamed: R315.1, R317.1, U302.2 (-)
unnamed: C312.1, R314.2, U302.5 (+)
unnamed: R316.1, R318.1, U302.6 (-)
unnamed: C315.1, R319.2, U302.10 (+)
unnamed: R321.1, R323.1, U302.9 (-)
unnamed: C316.1, R320.2, U302.12 (+)
unnamed: R322.1, R324.1, U302.13 (-)

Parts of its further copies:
C401, C402, C403, C404, C406, C407, C409, C410, C411, C412, C413, C414, C415, C416, C417, C418, C501, C502, C503, C504, C506, C507, C509, C510, C511, C512, C513, C514, C515, C516, C517, C518, C601, C602, C603, C604, C606, C607, C609, C610, C611, C612, C613, C614, C615, C616, C617, C618: 1.8n; C_0603_1608Metric
C405, C408, C505, C508, C605, C608: 100n; C_0603_1608Metric
R401, R402, R403, R404, R407, R408, R409, R410, R413, R414, R415, R416, R419, R420, R421, R422, R501, R502, R503, R504, R507, R508, R509, R510, R513, R514, R515, R516, R519, R520, R521, R522, R601, R602, R603, R604, R607, R608, R609, R610, R613, R614, R615, R616, R619, R620, R621, R622: 1k; R_0603_1608Metric
R405, R406, R411, R412, R417, R418, R423, R424, R505, R506, R511, R512, R517, R518, R523, R524, R605, R606, R611, R612, R617, R618, R623, R624: 15k; R_0603_1608Metric
U401, U402, U501, U502, U601, U602: TSV994; SOIC-14_3.9x8.7mm_P1.27mm

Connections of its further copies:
1.65V: C403.2, C404.2, C409.2, C410.2, C413.2, C414.2, C417.2, C418.2, C503.2, C504.2, C509.2, C510.2, C513.2, C514.2, C517.2, C518.2, C603.2, C604.2, C609.2, C610.2, C613.2, C614.2, C617.2, C618.2, R401.1, R402.1, R407.1, R408.1, R413.1, R414.1, R419.1, R420.1, R501.1, R502.1, R507.1, R508.1, R513.1, R514.1, R519.1, R520.1, R601.1, R602.1, R607.1, R608.1, R613.1, R614.1, R619.1, R620.1; also elsewhere on the board
+3.3VA: C405.1, C408.1, C505.1, C508.1, C605.1, C608.1, U401.4 (V+), U402.4 (V+), U501.4 (V+), U502.4 (V+), U601.4 (V+), U602.4 (V+); also elsewhere on the board
/Mux & Amplifier 1/In9: R405.2, U401.1; also elsewhere on the board
/Mux & Amplifier 1/In10: R406.2, U401.7; also elsewhere on the board
/Mux & Amplifier 1/In11: R411.2, U401.8; also elsewhere on the board
/Mux & Amplifier 1/In12: R412.2, U401.14; also elsewhere on the board
/Mux & Amplifier 1/In13: R417.2, U402.1; also elsewhere on the board
/Mux & Amplifier 1/In14: R418.2, U402.7; also elsewhere on the board
/Mux & Amplifier 1/In15: R423.2, U402.8; also elsewhere on the board
/Mux & Amplifier 1/In16: R424.2, U402.14; also elsewhere on the board
/Mux & Amplifier 2/In1: R505.2, U501.1; also elsewhere on the board
/Mux & Amplifier 2/In2: R506.2, U501.7; also elsewhere on the board
/Mux & Amplifier 2/In3: R511.2, U501.8; also elsewhere on the board
/Mux & Amplifier 2/In4: R512.2, U501.14; also elsewhere on the board
/Mux & Amplifier 2/In5: R517.2, U502.1; also elsewhere on the board
/Mux & Amplifier 2/In6: R518.2, U502.7; also elsewhere on the board
/Mux & Amplifier 2/In7: R523.2, U502.8; also elsewhere on the board
/Mux & Amplifier 2/In8: R524.2, U502.14; also elsewhere on the board
/Mux & Amplifier 2/In9: R605.2, U601.1; also elsewhere on the board
/Mux & Amplifier 2/In10: R606.2, U601.7; also elsewhere on the board
/Mux & Amplifier 2/In11: R611.2, U601.8; also elsewhere on the board
/Mux & Amplifier 2/In12: R612.2, U601.14; also elsewhere on the board
/Mux & Amplifier 2/In13: R617.2, U602.1; also elsewhere on the board
/Mux & Amplifier 2/In14: R618.2, U602.7; also elsewhere on the board
/Mux & Amplifier 2/In15: R623.2, U602.8; also elsewhere on the board
/Mux & Amplifier 2/In16: R624.2, U602.14; also elsewhere on the board
/Receiver Stage/Rx Row Amplifier 2/RXIN1: C401.2; also elsewhere on the board
/Receiver Stage/Rx Row Amplifier 2/RXIN2: C402.2; also elsewhere on the board
/Receiver Stage/Rx Row Amplifier 2/RXIN3: C406.2; also elsewhere on the board
/Receiver Stage/Rx Row Amplifier 2/RXIN4: C407.2; also elsewhere on the board
/Receiver Stage/Rx Row Amplifier 2/RXIN5: C411.2; also elsewhere on the board
/Receiver Stage/Rx Row Amplifier 2/RXIN6: C412.2; also elsewhere on the board
/Receiver Stage/Rx Row Amplifier 2/RXIN7: C415.2; also elsewhere on the board
/Receiver Stage/Rx Row Amplifier 2/RXIN8: C416.2; also elsewhere on the board
/Receiver Stage/Rx Row Amplifier 3/RXIN1: C501.2; also elsewhere on the board
/Receiver Stage/Rx Row Amplifier 3/RXIN2: C502.2; also elsewhere on the board
/Receiver Stage/Rx Row Amplifier 3/RXIN3: C506.2; also elsewhere on the board
/Receiver Stage/Rx Row Amplifier 3/RXIN4: C507.2; also elsewhere on the board
/Receiver Stage/Rx Row Amplifier 3/RXIN5: C511.2; also elsewhere on the board
/Receiver Stage/Rx Row Amplifier 3/RXIN6: C512.2; also elsewhere on the board
/Receiver Stage/Rx Row Amplifier 3/RXIN7: C515.2; also elsewhere on the board
/Receiver Stage/Rx Row Amplifier 3/RXIN8: C516.2; also elsewhere on the board
/Receiver Stage/Rx Row Amplifier 4/RXIN1: C601.2; also elsewhere on the board
/Receiver Stage/Rx Row Amplifier 4/RXIN2: C602.2; also elsewhere on the board
/Receiver Stage/Rx Row Amplifier 4/RXIN3: C606.2; also elsewhere on the board
/Receiver Stage/Rx Row Amplifier 4/RXIN4: C607.2; also elsewhere on the board
/Receiver Stage/Rx Row Amplifier 4/RXIN5: C611.2; also elsewhere on the board
/Receiver Stage/Rx Row Amplifier 4/RXIN6: C612.2; also elsewhere on the board
/Receiver Stage/Rx Row Amplifier 4/RXIN7: C615.2; also elsewhere on the board
/Receiver Stage/Rx Row Amplifier 4/RXIN8: C616.2; also elsewhere on the board
GND: C405.2, C408.2, C505.2, C508.2, C605.2, C608.2, U401.11 (V-), U402.11 (V-), U501.11 (V-), U502.11 (V-), U601.11 (V-), U602.11 (V-); also elsewhere on the board
unnamed: C403.1, R403.2
unnamed: C404.1, R404.2
unnamed: C409.1, R409.2
unnamed: C410.1, R410.2
unnamed: C413.1, R415.2
unnamed: C414.1, R416.2
unnamed: C417.1, R421.2
unnamed: C418.1, R422.2
unnamed: C503.1, R503.2
unnamed: C504.1, R504.2
unnamed: C509.1, R509.2
unnamed: C510.1, R510.2
unnamed: C513.1, R515.2
unnamed: C514.1, R516.2
unnamed: C517.1, R521.2
unnamed: C518.1, R522.2
unnamed: C603.1, R603.2
unnamed: C604.1, R604.2
unnamed: C609.1, R609.2
unnamed: C610.1, R610.2
unnamed: C613.1, R615.2
unnamed: C614.1, R616.2
unnamed: C617.1, R621.2
unnamed: C618.1, R622.2
unnamed: C401.1, R401.2, U401.3 (+)
unnamed: R403.1, R405.1, U401.2 (-)
unnamed: C402.1, R402.2, U401.5 (+)
unnamed: R404.1, R406.1, U401.6 (-)
unnamed: C406.1, R407.2, U401.10 (+)
unnamed: R409.1, R411.1, U401.9 (-)
unnamed: C407.1, R408.2, U401.12 (+)
unnamed: R410.1, R412.1, U401.13 (-)
unnamed: C411.1, R413.2, U402.3 (+)
unnamed: R415.1, R417.1, U402.2 (-)
unnamed: C412.1, R414.2, U402.5 (+)
unnamed: R416.1, R418.1, U402.6 (-)
unnamed: C415.1, R419.2, U402.10 (+)
unnamed: R421.1, R423.1, U402.9 (-)
unnamed: C416.1, R420.2, U402.12 (+)
unnamed: R422.1, R424.1, U402.13 (-)
unnamed: C501.1, R501.2, U501.3 (+)
unnamed: R503.1, R505.1, U501.2 (-)
unnamed: C502.1, R502.2, U501.5 (+)
unnamed: R504.1, R506.1, U501.6 (-)
unnamed: C506.1, R507.2, U501.10 (+)
unnamed: R509.1, R511.1, U501.9 (-)
unnamed: C507.1, R508.2, U501.12 (+)
unnamed: R510.1, R512.1, U501.13 (-)
unnamed: C511.1, R513.2, U502.3 (+)
unnamed: R515.1, R517.1, U502.2 (-)
unnamed: C512.1, R514.2, U502.5 (+)
unnamed: R516.1, R518.1, U502.6 (-)
unnamed: C515.1, R519.2, U502.10 (+)
unnamed: R521.1, R523.1, U502.9 (-)
unnamed: C516.1, R520.2, U502.12 (+)
unnamed: R522.1, R524.1, U502.13 (-)
unnamed: C601.1, R601.2, U601.3 (+)
unnamed: R603.1, R605.1, U601.2 (-)
unnamed: C602.1, R602.2, U601.5 (+)
unnamed: R604.1, R606.1, U601.6 (-)
unnamed: C606.1, R607.2, U601.10 (+)
unnamed: R609.1, R611.1, U601.9 (-)
unnamed: C607.1, R608.2, U601.12 (+)
unnamed: R610.1, R612.1, U601.13 (-)
unnamed: C611.1, R613.2, U602.3 (+)
unnamed: R615.1, R617.1, U602.2 (-)
unnamed: C612.1, R614.2, U602.5 (+)
unnamed: R616.1, R618.1, U602.6 (-)
unnamed: C615.1, R619.2, U602.10 (+)
unnamed: R621.1, R623.1, U602.9 (-)
unnamed: C616.1, R620.2, U602.12 (+)
unnamed: R622.1, R624.1, U602.13 (-)

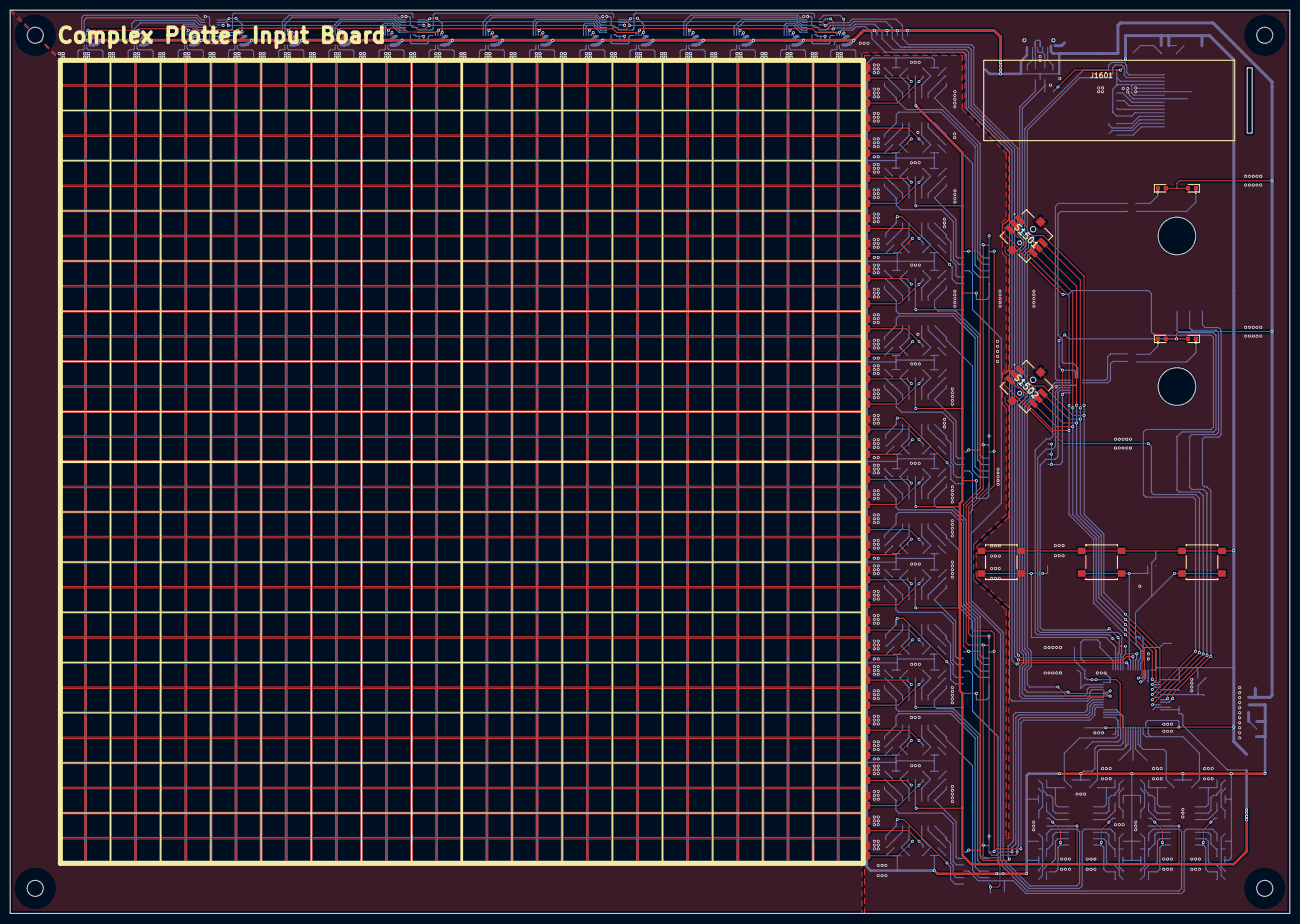
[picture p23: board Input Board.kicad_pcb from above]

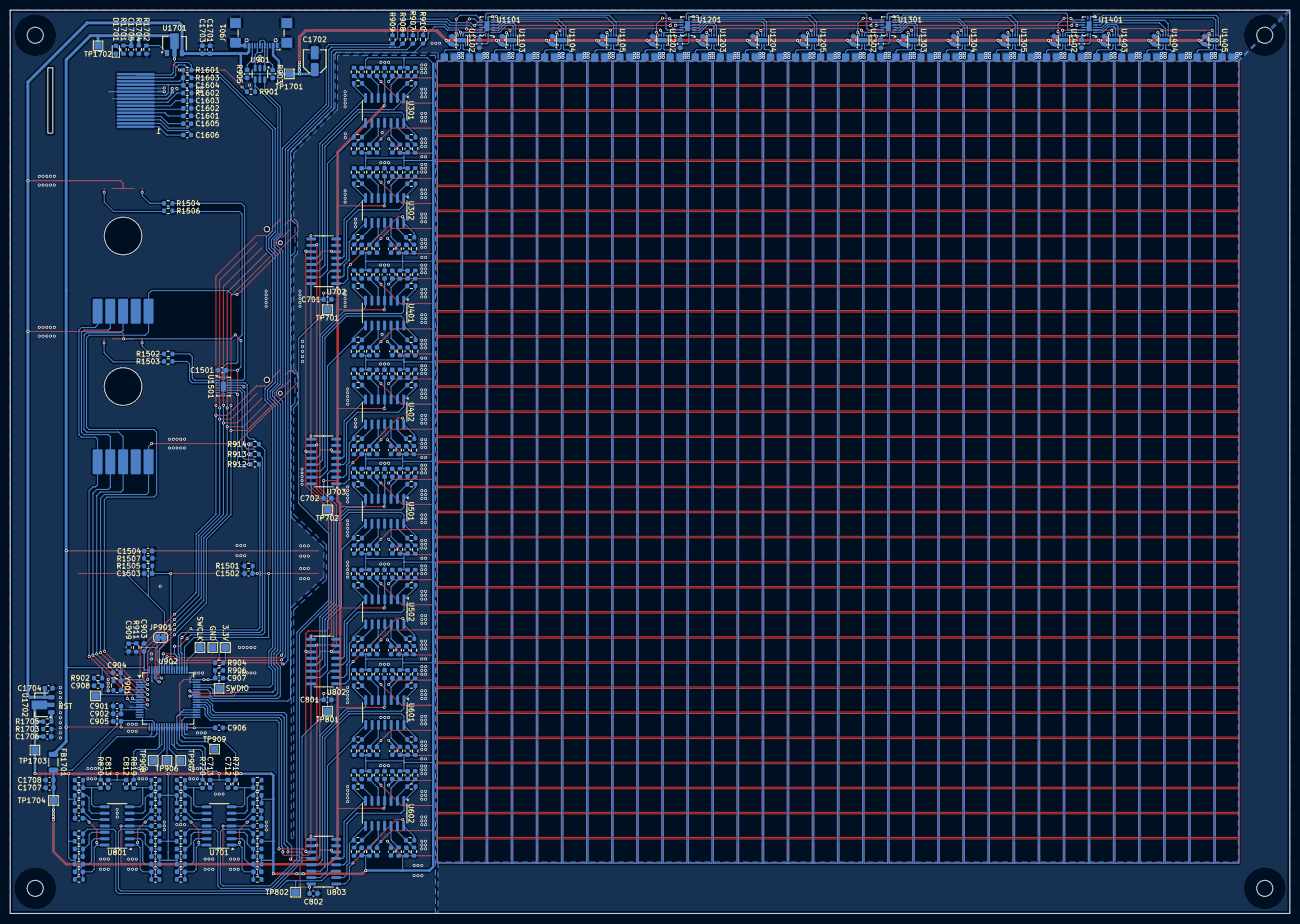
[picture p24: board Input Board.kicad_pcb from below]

Board: 2 copper layers, 255.0 x 180.0 mm, 451 parts (403 on the bottom side), 331 nets.

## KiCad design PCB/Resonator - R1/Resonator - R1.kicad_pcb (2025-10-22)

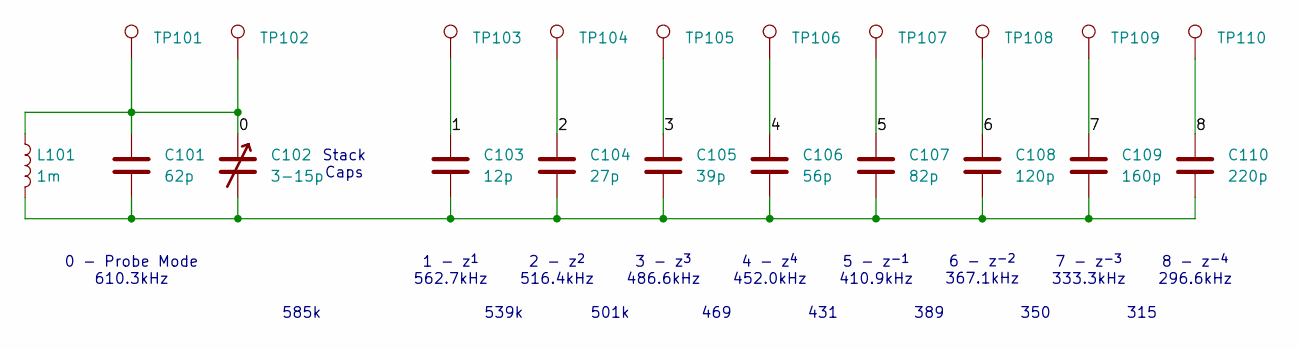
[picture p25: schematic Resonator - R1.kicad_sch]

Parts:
C101: 62p; C_0603_1608Metric
C102: 3-15p
C103: 12p; C_0603_1608Metric
C104: 27p; C_0603_1608Metric
C105: 39p; C_0603_1608Metric
C106: 56p; C_0603_1608Metric
C107: 82p; C_0603_1608Metric
C108: 120p; C_0603_1608Metric
C109: 160p; C_0603_1608Metric
C110: 220p; C_0603_1608Metric
L101: 1m; L
TP101, TP102: TestPoint; 5mm 112.5
TP103, TP104, TP105, TP106, TP107, TP108, TP109, TP110: TestPoint; 7mm 20

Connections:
/0: C101.1, C102.1, L101.1, TP101.1, TP102.1
/1: C103.1, TP103.1
/2: C104.1, TP104.1
/3: C105.1, TP105.1
/4: C106.1, TP106.1
/5: C107.1, TP107.1
/6: C108.1, TP108.1
/7: C109.1, TP109.1
/8: C110.1, TP110.1
unnamed: C101.2, C102.2, C103.2, C104.2, C105.2, C106.2, C107.2, C108.2, C109.2, C110.2, L101.2

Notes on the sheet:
8 - z^{-4} 296.6kHz
0 - Probe Mode 610.3kHz
469
Stack Caps
3 - z^{3} 486.6kHz
389
2 - z^{2} 516.4kHz
1 - z^{1} 562.7kHz
4 - z^{4} 452.0kHz
431
5 - z^{-1} 410.9kHz
7 - z^{-3} 333.3kHz
350
315
501k
6 - z^{-2} 367.1kHz
539k
585k

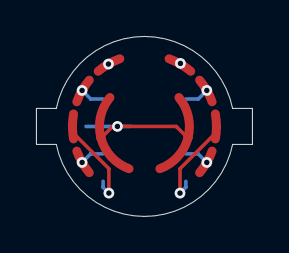
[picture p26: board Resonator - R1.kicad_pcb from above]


Board: 2 copper layers, 12.0 x 10.0 mm, 20 parts (10 on the bottom side), 10 nets.

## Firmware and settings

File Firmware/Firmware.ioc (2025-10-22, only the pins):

Mcu.UserName=STM32F303RBTx
PA10.GPIO_Label=OLED_SDA
PA10.Signal=I2C2_SDA
PA11.Signal=USB_DM
PA12.Signal=USB_DP
PA13.Signal=SYS_JTMS-SWDIO
PA14.Signal=SYS_JTCK-SWCLK
PA15.GPIO_Label=PUSH_1
PA15.Signal=GPIO_Input
PA4.GPIO_Label=RX1_COMP
PA4.Signal=COMP3_INM
PA5.GPIO_Label=RX3_COMP
PA5.Signal=COMP5_INM
PA6.GPIO_Label=RX3_ADC
PA6.Signal=ADC2_IN3
PA7.GPIO_Label=TP908
PA7.Signal=GPIO_Output
PA8.GPIO_Label=TX_SLEEP
PA8.Signal=GPIO_Output
PA9.GPIO_Label=OLED_SCL
PA9.Signal=I2C2_SCL
PB0.GPIO_Label=RX2_COMP
PB0.Signal=COMP4_INP
PB1.GPIO_Label=RX2_ADC
PB1.Signal=ADC3_IN1
PB10.GPIO_Label=TP909
PB10.Signal=GPIO_Output
PB11.GPIO_Label=RX4_COMP
PB11.Signal=COMP6_INP
PB12.GPIO_Label=RX4_ADC
PB12.Signal=ADC4_IN3
PB13.GPIO_Label=VREF
PB13.Signal=COMP5_INP
PB14.GPIO_Label=VREF
PB14.Signal=COMP3_INP
PB15.GPIO_Label=VREF
PB15.Signal=COMP6_INM
PB2.GPIO_Label=VREF
PB2.Signal=COMP4_INM
PB3.GPIO_Label=TX_CLK
PB3.Signal=SPI1_SCK
PB4.GPIO_Label=PUSH_2
PB4.Signal=GPIO_Output
PB5.GPIO_Label=TX_MOSI
PB5.Signal=SPI1_MOSI
PB6.GPIO_Label=TX_RCLK
PB6.Signal=GPIO_Output
PB7.GPIO_Label=PUSH_3
PB7.Signal=GPIO_Input
PB8.GPIO_Label=OFFSET_LEFT
PB8.Signal=GPIO_Input
PB9.GPIO_Label=OFFSET_DOWN
PB9.Signal=GPIO_Input
PC0.GPIO_Label=OFFSET_COM
PC0.Signal=GPIO_Output
PC1.GPIO_Label=SCALE_B
PC1.Signal=GPIO_Input
PC10.GPIO_Label=UI_SCK
PC10.Signal=SPI3_SCK
PC11.GPIO_Label=UI_RCLK
PC11.Signal=GPIO_Output
PC12.GPIO_Label=UI_MOSI
PC12.Signal=SPI3_MOSI
PC13.GPIO_Label=OFFSET_CENTER
PC13.Signal=GPIO_Input
PC14-OSC32_IN.GPIO_Label=OFFSET_RIGHT
PC14-OSC32_IN.Signal=GPIO_Input
PC15-OSC32_OUT.GPIO_Label=OFFSET_UP
PC15-OSC32_OUT.Signal=GPIO_Input
PC2.GPIO_Label=SCALE_A
PC2.Signal=GPIO_Input
PC3.GPIO_Label=SCALE_PUSH
PC3.Signal=GPIO_Input
PC4.GPIO_Label=TP906
PC4.Signal=GPIO_Output
PC5.GPIO_Label=TP907
PC5.Signal=GPIO_Output
PC6.GPIO_Label=MUX_A
PC6.Signal=GPIO_Output
PC7.GPIO_Label=MUX_B
PC7.Signal=GPIO_Output
PC8.GPIO_Label=MUX_C
PC8.Signal=GPIO_Output
PC9.GPIO_Label=MUX_INHIBIT
PC9.Signal=GPIO_Output
PF0-OSC_IN.Signal=RCC_OSC_IN
PF1-OSC_OUT.GPIO_Label=INPUT_COM
PF1-OSC_OUT.Signal=GPIO_Output
PF4.GPIO_Label=RX1_ADC
PF4.Signal=ADC1_IN5

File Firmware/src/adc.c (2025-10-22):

/**
******************************************************************************
* @file    adc.c
* @brief   This file provides code for the configuration
*          of the ADC instances.
******************************************************************************
* @attention
*
* Copyright (c) 2025 STMicroelectronics.
* All rights reserved.
*
* This software is licensed under terms that can be found in the LICENSE file
* in the root directory of this software component.
* If no LICENSE file comes with this software, it is provided AS-IS.
*
******************************************************************************
*/
#include "adc.h"

ADC_HandleTypeDef hadc1;
ADC_HandleTypeDef hadc2;
ADC_HandleTypeDef hadc3;
ADC_HandleTypeDef hadc4;
DMA_HandleTypeDef hdma_adc1;
DMA_HandleTypeDef hdma_adc2;
DMA_HandleTypeDef hdma_adc3;
DMA_HandleTypeDef hdma_adc4;

void MX_ADC1_Init(void)
{
  ADC_MultiModeTypeDef multimode = {0};
  ADC_ChannelConfTypeDef sConfig = {0};

  /** Common config */
  hadc1.Instance = ADC1;
  hadc1.Init.ClockPrescaler = ADC_CLOCK_SYNC_PCLK_DIV2;
  hadc1.Init.Resolution = ADC_RESOLUTION_12B;
  hadc1.Init.ScanConvMode = ADC_SCAN_DISABLE;
  hadc1.Init.ContinuousConvMode = ENABLE;
  hadc1.Init.DiscontinuousConvMode = DISABLE;
  hadc1.Init.ExternalTrigConvEdge = ADC_EXTERNALTRIGCONVEDGE_NONE;
  hadc1.Init.ExternalTrigConv = ADC_SOFTWARE_START;
  hadc1.Init.DataAlign = ADC_DATAALIGN_LEFT;
  hadc1.Init.NbrOfConversion = 1;
  hadc1.Init.DMAContinuousRequests = DISABLE;
  hadc1.Init.EOCSelection = ADC_EOC_SINGLE_CONV;
  hadc1.Init.LowPowerAutoWait = DISABLE;
  hadc1.Init.Overrun = ADC_OVR_DATA_OVERWRITTEN;
  if (HAL_ADC_Init(&hadc1) != HAL_OK)
  {
    Error_Handler();
  }

  /** Configure the ADC multi-mode
  */
  multimode.Mode = ADC_MODE_INDEPENDENT;
  if (HAL_ADCEx_MultiModeConfigChannel(&hadc1, &multimode) != HAL_OK)
  {
    Error_Handler();
  }

  /** Configure Regular Channel
  */
  sConfig.Channel = ADC_CHANNEL_5;
  sConfig.Rank = ADC_REGULAR_RANK_1;
  sConfig.SingleDiff = ADC_SINGLE_ENDED;
  sConfig.SamplingTime = ADC_SAMPLETIME_1CYCLE_5;
  sConfig.OffsetNumber = ADC_OFFSET_1;
  sConfig.Offset = 2048;
  if (HAL_ADC_ConfigChannel(&hadc1, &sConfig) != HAL_OK)
  {
    Error_Handler();
  }
}
/* ADC2 init function */
void MX_ADC2_Init(void)
{
  ADC_ChannelConfTypeDef sConfig = {0};

  /** Common config
  */
  hadc2.Instance = ADC2;
  hadc2.Init.ClockPrescaler = ADC_CLOCK_SYNC_PCLK_DIV2;
  hadc2.Init.Resolution = ADC_RESOLUTION_12B;
  hadc2.Init.ScanConvMode = ADC_SCAN_DISABLE;
  hadc2.Init.ContinuousConvMode = ENABLE;
  hadc2.Init.DiscontinuousConvMode = DISABLE;
  hadc2.Init.ExternalTrigConvEdge = ADC_EXTERNALTRIGCONVEDGE_NONE;
  hadc2.Init.ExternalTrigConv = ADC_SOFTWARE_START;
  hadc2.Init.DataAlign = ADC_DATAALIGN_LEFT;
  hadc2.Init.NbrOfConversion = 1;
  hadc2.Init.DMAContinuousRequests = DISABLE;
  hadc2.Init.EOCSelection = ADC_EOC_SINGLE_CONV;
  hadc2.Init.LowPowerAutoWait = DISABLE;
  hadc2.Init.Overrun = ADC_OVR_DATA_OVERWRITTEN;
  if (HAL_ADC_Init(&hadc2) != HAL_OK)
  {
    Error_Handler();
  }

  /** Configure Regular Channel
  */
  sConfig.Channel = ADC_CHANNEL_3;
  sConfig.Rank = ADC_REGULAR_RANK_1;
  sConfig.SingleDiff = ADC_SINGLE_ENDED;
  sConfig.SamplingTime = ADC_SAMPLETIME_1CYCLE_5;
  sConfig.OffsetNumber = ADC_OFFSET_1;
  sConfig.Offset = 2048;
  if (HAL_ADC_ConfigChannel(&hadc2, &sConfig) != HAL_OK)
  {
    Error_Handler();
  }
}
/* ADC3 init function */
void MX_ADC3_Init(void)
{
  ADC_MultiModeTypeDef multimode = {0};
  ADC_ChannelConfTypeDef sConfig = {0};

  /** Common config
  */
  hadc3.Instance = ADC3;
  hadc3.Init.ClockPrescaler = ADC_CLOCK_SYNC_PCLK_DIV2;
  hadc3.Init.Resolution = ADC_RESOLUTION_12B;
  hadc3.Init.ScanConvMode = ADC_SCAN_DISABLE;
  hadc3.Init.ContinuousConvMode = ENABLE;
  hadc3.Init.DiscontinuousConvMode = DISABLE;
  hadc3.Init.ExternalTrigConvEdge = ADC_EXTERNALTRIGCONVEDGE_NONE;
  hadc3.Init.ExternalTrigConv = ADC_SOFTWARE_START;
  hadc3.Init.DataAlign = ADC_DATAALIGN_LEFT;
  hadc3.Init.NbrOfConversion = 1;
  hadc3.Init.DMAContinuousRequests = DISABLE;
  hadc3.Init.EOCSelection = ADC_EOC_SINGLE_CONV;
  hadc3.Init.LowPowerAutoWait = DISABLE;
  hadc3.Init.Overrun = ADC_OVR_DATA_OVERWRITTEN;
  if (HAL_ADC_Init(&hadc3) != HAL_OK)
  {
    Error_Handler();
  }

  /** Configure the ADC multi-mode
  */
  multimode.Mode = ADC_MODE_INDEPENDENT;
  if (HAL_ADCEx_MultiModeConfigChannel(&hadc3, &multimode) != HAL_OK)
  {
    Error_Handler();
  }

  /** Configure Regular Channel
  */
  sConfig.Channel = ADC_CHANNEL_1;
  sConfig.Rank = ADC_REGULAR_RANK_1;
  sConfig.SingleDiff = ADC_SINGLE_ENDED;
  sConfig.SamplingTime = ADC_SAMPLETIME_1CYCLE_5;
  sConfig.OffsetNumber = ADC_OFFSET_1;
  sConfig.Offset = 2048;
  if (HAL_ADC_ConfigChannel(&hadc3, &sConfig) != HAL_OK)
  {
    Error_Handler();
  }
}
/* ADC4 init function */
void MX_ADC4_Init(void)
{
  ADC_ChannelConfTypeDef sConfig = {0};

  /** Common config
  */
  hadc4.Instance = ADC4;
  hadc4.Init.ClockPrescaler = ADC_CLOCK_SYNC_PCLK_DIV2;
  hadc4.Init.Resolution = ADC_RESOLUTION_12B;
  hadc4.Init.ScanConvMode = ADC_SCAN_DISABLE;
  hadc4.Init.ContinuousConvMode = ENABLE;
  hadc4.Init.DiscontinuousConvMode = DISABLE;
  hadc4.Init.ExternalTrigConvEdge = ADC_EXTERNALTRIGCONVEDGE_NONE;
  hadc4.Init.ExternalTrigConv = ADC_SOFTWARE_START;
  hadc4.Init.DataAlign = ADC_DATAALIGN_LEFT;
  hadc4.Init.NbrOfConversion = 1;
  hadc4.Init.DMAContinuousRequests = DISABLE;
  hadc4.Init.EOCSelection = ADC_EOC_SINGLE_CONV;
  hadc4.Init.LowPowerAutoWait = DISABLE;
  hadc4.Init.Overrun = ADC_OVR_DATA_OVERWRITTEN;
  if (HAL_ADC_Init(&hadc4) != HAL_OK)
  {
    Error_Handler();
  }

  /** Configure Regular Channel
  */
  sConfig.Channel = ADC_CHANNEL_3;
  sConfig.Rank = ADC_REGULAR_RANK_1;
  sConfig.SingleDiff = ADC_SINGLE_ENDED;
  sConfig.SamplingTime = ADC_SAMPLETIME_1CYCLE_5;
  sConfig.OffsetNumber = ADC_OFFSET_1;
  sConfig.Offset = 2048;
  if (HAL_ADC_ConfigChannel(&hadc4, &sConfig) != HAL_OK)
  {
    Error_Handler();
  }
}

static uint32_t HAL_RCC_ADC12_CLK_ENABLED=0;
static uint32_t HAL_RCC_ADC34_CLK_ENABLED=0;
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
